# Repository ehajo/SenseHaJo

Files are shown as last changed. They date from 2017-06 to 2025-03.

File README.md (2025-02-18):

# SenseHaJo
Alle Infos über das SenseHaJo Projekt.

Die Youtube-Livestream Playlist befindet sich hier: <a href="https://www.youtube.com/playlist?list=PLOau4iU1BNa8n_ICx9ISsTIcdp01ndQ__">Playlist on Youtube</a>

Livestreams immer hier auf Twitch: <a href="https://www.twitch.tv/ehajo">Link zu Twitch</a>

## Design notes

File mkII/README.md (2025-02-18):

# SenseHaJo

Mark II ist die aktuellste Version des SenseHaJo-Projekts. Mathias aka Calm aka "der andere" hat in KiCAD ein komplettes Projekt hochgezogen.

Ich programmiere die Software mit ESPHome und mit Hilfe von ChatGPT.

Die Platine besitzt nun einen leistungsstarken ESP32 Prozessor.

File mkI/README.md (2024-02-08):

# SenseHaJo mkI

Mark 1 ist der erste Wurf der SenseHaJo. Wir haben die gesamte Hardware reverse engineered und eine komplett eigene Platine gebaut, die exakt in die original Maschine passt.

Aus historischen Gründen befindet sich noch ein Atmega32u2 auf der Platine, der ESP war damals noch nicht weit genug entwickelt, als dass das Sinn gemacht hätte.

Die gesamte Maschine ist galvanisch getrennt und hat einen USB-Anschluss zur zusätzlichen Ansteuerung über zB eine Hausautomatisierung.

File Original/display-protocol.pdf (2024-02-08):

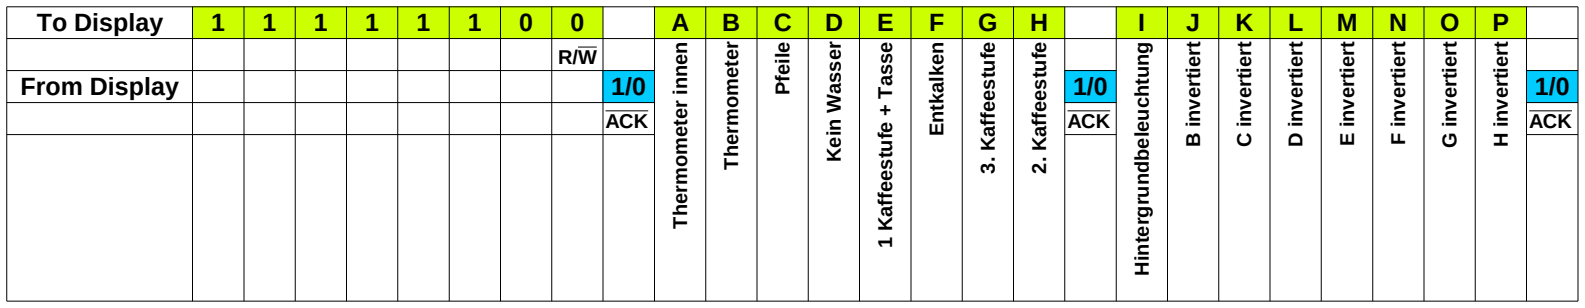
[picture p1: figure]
Thermometer innen; Thermometer; Pfeile; Kein Wasser; 1 Kaffeestufe + Tasse; Entkalken; 3. Kaffeestufe; 2. Kaffeestufe; Hintergrundbeleuchtung; B invertiert; C invertiert; D invertiert; E invertiert; F invertiert; G invertiert; H invertiert; ACK

To Display | 1 | 1 | 1 | 1 | 1 | 1 | 0 | 0 | | A | B | C | D | E | F | G | H | | I | J | K | L | M | N | O | P
From Display | | | | | | | | | 1/0 | | | | | | | | | 1/0 | | | | | | | | | 1/0

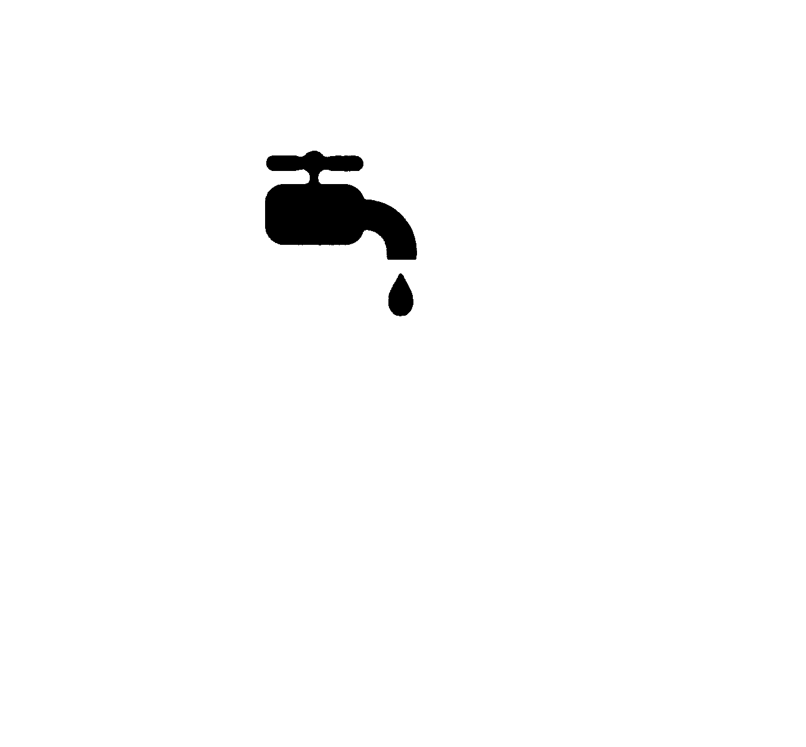
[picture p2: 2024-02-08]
Original/display-bilder/wasser-aus.png

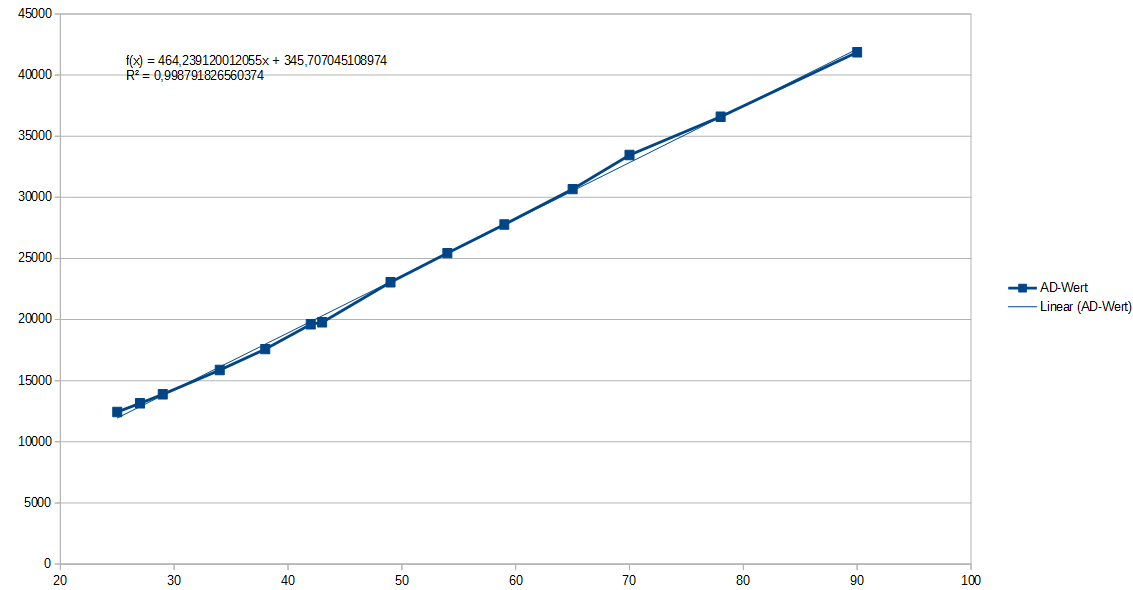
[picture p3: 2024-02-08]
Original/adc-temp.PNG

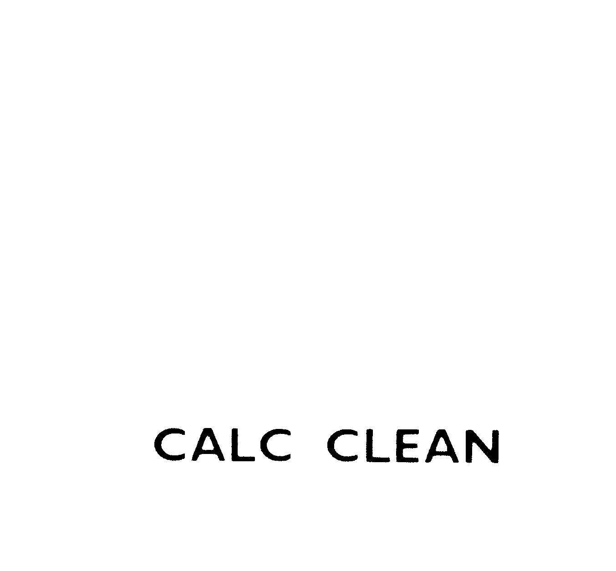
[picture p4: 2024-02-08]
Original/display-bilder/calcclean.png

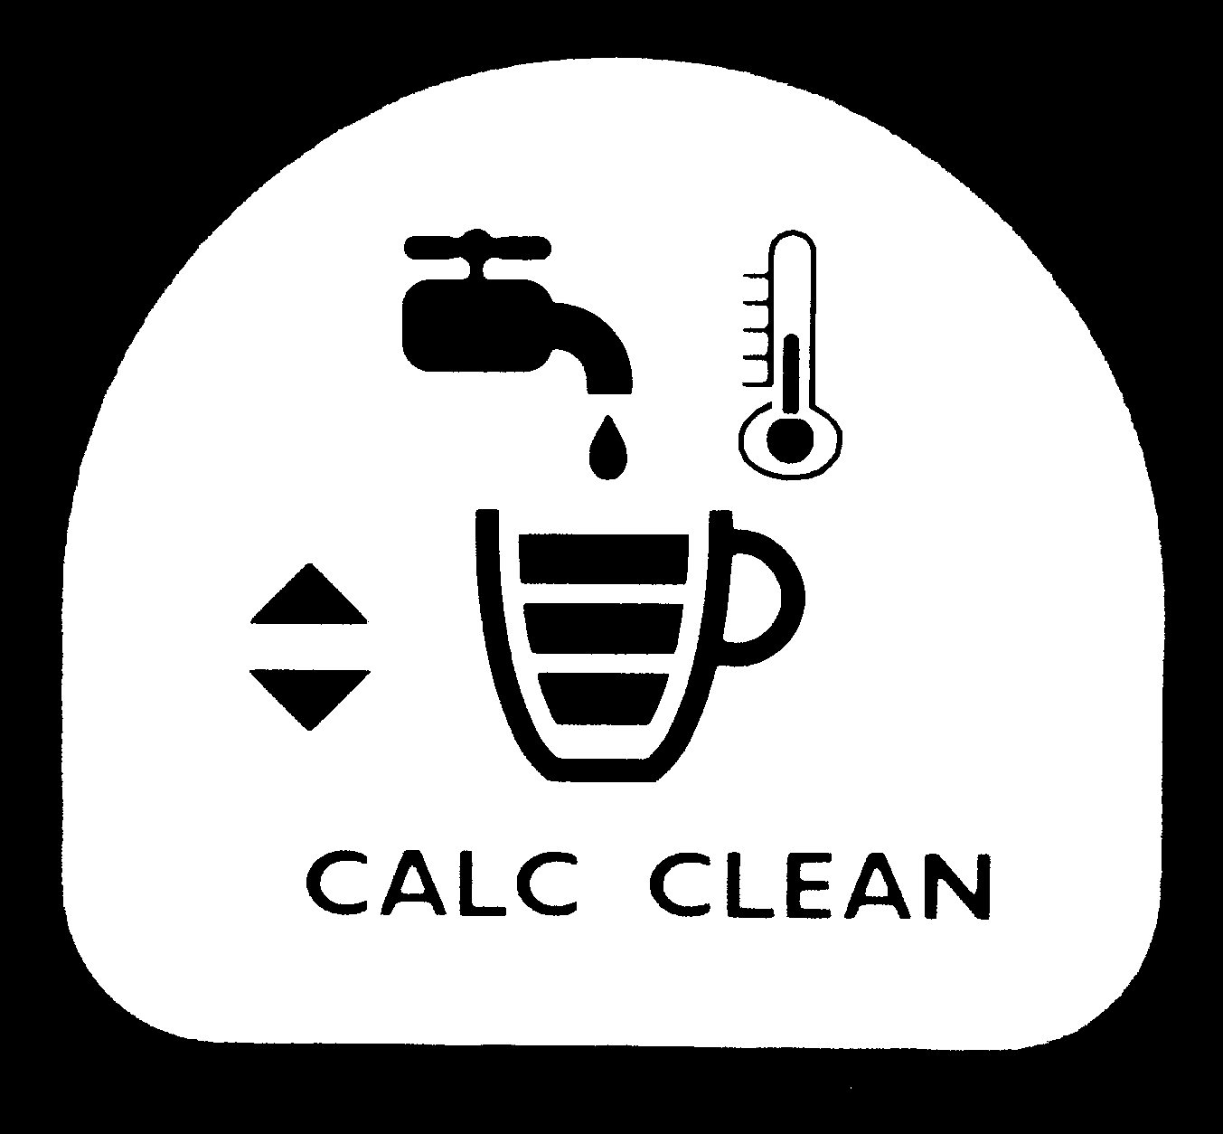
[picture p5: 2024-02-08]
Original/display-bilder/alles-an.png

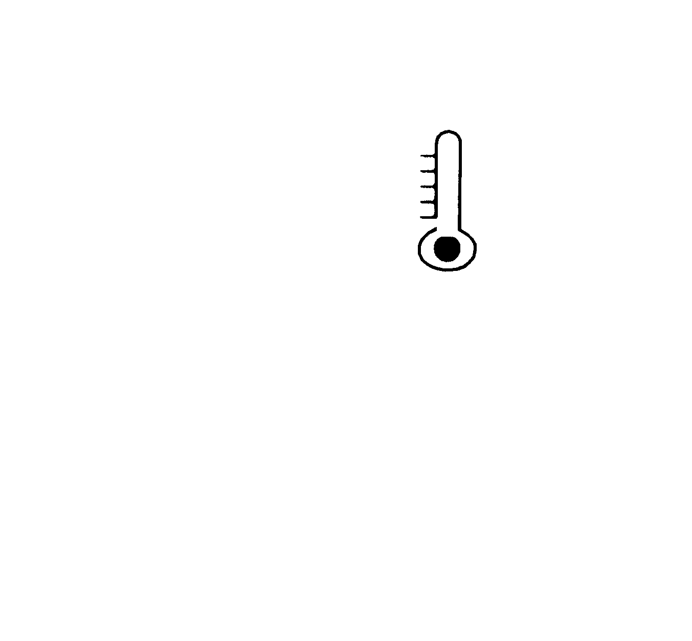
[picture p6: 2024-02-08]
Original/display-bilder/temp-2.png

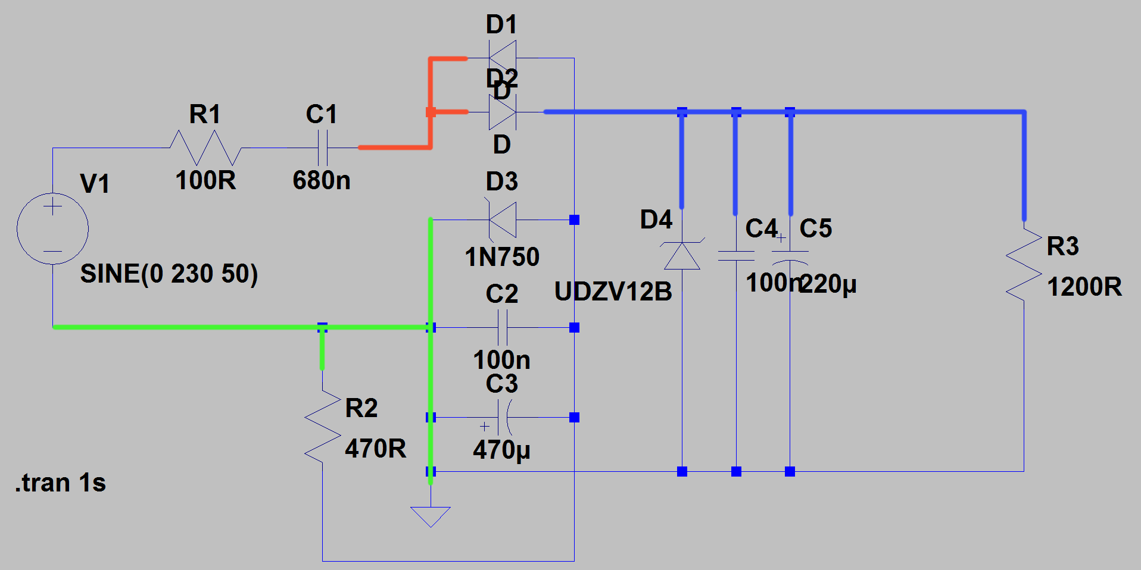
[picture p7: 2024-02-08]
Original/Simulation/schaltung.png

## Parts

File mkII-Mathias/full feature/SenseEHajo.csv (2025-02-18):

Source: | D:\NextCloud\KiCad\SensEhajo-KiCad\SenseEHajo\SenseEHajo.kicad_sch
Date: | 6/11/2023 4:29:25 PM
Tool: | Eeschema 7.0.1
Generator: | C:\Program Files\KiCad\6.0\bin\scripting\plugins/bom_csv_grouped_by_value_with_fp.py
Component Count: | 103
Ref | Qnty | Value | Cmp name | Footprint | Description | Vendor
C1, C3, | 2 | 1uF / 10V | C_Small | Capacitor_SMD:C_0805_2012Metric_Pad1.18x1.45mm_HandSolder | Unpolarized capacitor, small symbol
C2, C4, C5, C6, C7, C8, C14, C15, C16, C17, C19, C25, C26, C27, C28, | 15 | 100nF / 10V | C_Small | Capacitor_SMD:C_0805_2012Metric_Pad1.18x1.45mm_HandSolder | Unpolarized capacitor, small symbol
C9, | 1 | 10uF/10V | CP1_Small | Capacitor_SMD:CP_Elec_4x4.5
C10, | 1 | 1uF/25V | C_Small | Capacitor_SMD:C_0805_2012Metric_Pad1.18x1.45mm_HandSolder | Unpolarized capacitor, small symbol
C11, | 1 | 47uF/10V | CP1_Small | Capacitor_SMD:CP_Elec_5x5.3
C12, | 1 | 1uF/25V | C_Small | Capacitor_SMD:C_0805_2012Metric_Pad1.18x1.45mm_HandSolder | Unpolarized capacitor, small symbol
C13, | 1 | 10uF/25V | C_Small | Capacitor_SMD:C_0805_2012Metric_Pad1.18x1.45mm_HandSolder | Unpolarized capacitor, small symbol
C18, | 1 | 10uF / 10V | C_Small | Capacitor_SMD:C_0805_2012Metric_Pad1.18x1.45mm_HandSolder | Unpolarized capacitor, small symbol
D2, | 1 | D_Schottky | D_Schottky | Diode_SMD:D_SOD-523 | Schottky diode
D3, D6, D7, | 3 | WS2812B | WS2812B | LED_SMD:LED_WS2812B_PLCC4_5.0x5.0mm_P3.2mm | RGB LED with integrated controller
D4, | 1 | 1N4006 | 1N4006 | Diode_THT:D_DO-201AD_P15.24mm_Horizontal | 800V 1A General Purpose Rectifier Diode, DO-41
D5, | 1 | PMEG4010EGWX | D_Schottky | Diode_SMD:D_SOD-123 | Schottky diode
FB1, FB2, | 2 | Ferrite_Bead | Ferrite_Bead | Resistor_SMD:R_0805_2012Metric_Pad1.20x1.40mm_HandSolder
IC1, | 1 | AP3012 | AP3012 | Package_TO_SOT_SMD:SOT-23-5_HandSoldering
IC2, | 1 | MCP3221 | MCP3221 | Package_TO_SOT_SMD:SOT-23-5_HandSoldering
IC3, IC5, IC6, | 3 | 74LVC1G125 | 74LVC1G125 | SC-74A_SOT753:SC-74A
IC4, | 1 | K814P | K814P | Package_DIP:DIP-4_W7.62mm
IC7, | 1 | 74LVC1G10 | 74LVC1G10 | Package_TO_SOT_SMD:SOT-23-6_Handsoldering
J1, | 1 | Conn_01x02_Male | Conn_01x02_Male | Connector_PinHeader_2.54mm:PinHeader_1x02_P2.54mm_Vertical | Generic connector, single row, 01x02, script generated (kicad-library-utils/schlib/autogen/connector/)
J2, | 1 | REED | Conn_01x02_Male | Connector_PinHeader_2.54mm:PinHeader_1x02_P2.54mm_Vertical | Generic connector, single row, 01x02, script generated (kicad-library-utils/schlib/autogen/connector/)
J3, | 1 | RTC ( DS3231) | Conn_01x05 | Connector_PinHeader_2.54mm:PinHeader_1x05_P2.54mm_Vertical | Generic connector, single row, 01x05, script generated (kicad-library-utils/schlib/autogen/connector/)
J4, | 1 | Heizung L | Conn_01x01_Male | MountingHole:MountingHole_2.7mm_M2.5_DIN965_Pad_TopBottom | Generic connector, single row, 01x01, script generated (kicad-library-utils/schlib/autogen/connector/)
J5, | 1 | Pumpe L | Conn_01x01_Male | MountingHole:MountingHole_2.7mm_M2.5_DIN965_Pad_TopBottom | Generic connector, single row, 01x01, script generated (kicad-library-utils/schlib/autogen/connector/)
J6, | 1 | Conn_01x05 | Conn_01x05 | Connector_PinHeader_2.54mm:PinHeader_1x05_P2.54mm_Vertical | Generic connector, single row, 01x05, script generated (kicad-library-utils/schlib/autogen/connector/)
J7, | 1 | L | Conn_01x01_Male | MountingHole:MountingHole_2.7mm_M2.5_DIN965_Pad_TopBottom | Generic connector, single row, 01x01, script generated (kicad-library-utils/schlib/autogen/connector/)
J8, | 1 | N | Conn_01x01_Male | MountingHole:MountingHole_2.7mm_M2.5_DIN965_Pad_TopBottom | Generic connector, single row, 01x01, script generated (kicad-library-utils/schlib/autogen/connector/)
J9, | 1 | Prog | Conn_01x05 | Connector_PinHeader_2.54mm:PinHeader_1x05_P2.54mm_Vertical | Generic connector, single row, 01x05, script generated (kicad-library-utils/schlib/autogen/connector/)
JP1, JP2, | 2 | Jumper_2_Open | Jumper_2_Open | Jumper:SolderJumper-2_P1.3mm_Open_RoundedPad1.0x1.5mm | Jumper, 2-pole, open
L1, | 1 | 10uH | L_Small | Inductor_SMD:L_Wuerth_MAPI-3015 | Inductor, small symbol
PS1, | 1 | HLK-PM01 | HLK-PM01 | Converter_ACDC:Converter_ACDC_HiLink_HLK-PMxx | Compact AC/DC board mount power module 3W 5V
Q1, | 1 | BSS138 | BSS138 | Package_TO_SOT_SMD:SOT-23 | 50V Vds, 0.22A Id, N-Channel MOSFET, SOT-23
R1, R5, R8, R9, R12, R13, R14, R21, R22, R24, R25, R26, R27, R28, R30, R31, R32, R33, R34, R35, R36, | 21 | 10k | R_Small | Resistor_SMD:R_0805_2012Metric_Pad1.20x1.40mm_HandSolder | Resistor, small symbol
R2, | 1 | 2k2 | R_Small | Resistor_SMD:R_0805_2012Metric_Pad1.20x1.40mm_HandSolder | Resistor, small symbol
R3, | 1 | 1k8 | R_Small | Resistor_SMD:R_0805_2012Metric_Pad1.20x1.40mm_HandSolder | Resistor, small symbol
R4, | 1 | 10k (DNP) | R_Small | Resistor_SMD:R_0805_2012Metric_Pad1.20x1.40mm_HandSolder | Resistor, small symbol
R6, R7, | 2 | 100k | R_Small | Resistor_THT:R_Axial_DIN0207_L6.3mm_D2.5mm_P7.62mm_Horizontal | Resistor, small symbol
R10, R11, | 2 | 150R | R_Small | Resistor_SMD:R_0805_2012Metric_Pad1.20x1.40mm_HandSolder | Resistor, small symbol
R15, R17, | 2 | 360R | R_Small | Resistor_THT:R_Axial_DIN0207_L6.3mm_D2.5mm_P7.62mm_Horizontal | Resistor, small symbol
R16, R18, | 2 | 330R | R_Small | Resistor_THT:R_Axial_DIN0207_L6.3mm_D2.5mm_P7.62mm_Horizontal | Resistor, small symbol
R20, R37, R38, R39, | 4 | 1k | R_Small | Resistor_SMD:R_0805_2012Metric_Pad1.20x1.40mm_HandSolder | Resistor, small symbol
R23, | 1 | 43.2k | R_Small | Resistor_SMD:R_0805_2012Metric_Pad1.20x1.40mm_HandSolder | Resistor, small symbol
R29, | 1 | 100R | R_Small | Resistor_SMD:R_0805_2012Metric_Pad1.20x1.40mm_HandSolder | Resistor, small symbol
SW2, | 1 | SW1 ( Boot ) | SW_Push | Button_Switch_THT:SW_PUSH_6mm | Push button switch, generic, two pins
SW3, | 1 | MACHINE_SW2 | SW_Push | Button_Switch_THT:SW_PUSH_6mm | Push button switch, generic, two pins
SW4, | 1 | MACHINE_SW3 | SW_Push | Button_Switch_THT:SW_PUSH_6mm | Push button switch, generic, two pins
T1, T2, | 2 | QJ8025 | QJ8025 | Package_TO_SOT_SMD:TO-263-3_TabPin2
TP1, TP2, | 2 | TestPoint | TestPoint | TestPoint:TestPoint_Pad_D2.0mm | test point
U1, | 1 | ESP32-WROOM-32 | ESP32-WROOM-32 | ESP32_Handsolder:ESP32-WROOM-32_HandSolder | RF Module, ESP32-D0WDQ6 SoC, Wi-Fi 802.11b/g/n, Bluetooth, BLE, 32-bit, 2.7-3.6V, onboard antenna, SMD
U2, U5, | 2 | MCP6001-OT | MCP6001-OT | Package_TO_SOT_SMD:SOT-23-5 | 1MHz, Low-Power Op Amp, SOT-23-5
U3, U4, | 2 | MOC3043M | MOC3043M | Package_DIP:DIP-6_W7.62mm | Zero Cross Opto-Triac, Vdrm 400V, Ift 5mA, DIP6
U6, | 1 | LM1117-3.3 | LM1117-3.3 | Package_TO_SOT_SMD:SOT-223-3_TabPin2 | 800mA Low-Dropout Linear Regulator, 3.3V fixed output, TO-220/TO-252/TO-263/SOT-223

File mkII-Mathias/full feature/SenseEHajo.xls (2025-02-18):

Ref | Qty | Value | Footprint | Datasheet | Order No. Farnell | Order No. Mouser
C1 C6 | 2 | 100nF / 25V | Capacitor_SMD:C_0805_2012Metric_Pad1.15x1.40mm_HandSolder | ~ |  | 710-885012207098
C2 C5 | 2 | 100nF / 10V | Capacitor_SMD:C_0805_2012Metric_Pad1.15x1.40mm_HandSolder | ~ |  | 710-885012207098
C3 | 1 | 1uF / 10V | Capacitor_SMD:C_0805_2012Metric_Pad1.15x1.40mm_HandSolder | ~ |  | 80-C0805C105Z4V
C4 | 1 | 10uF / 25V | Capacitor_SMD:C_0805_2012Metric_Pad1.15x1.40mm_HandSolder | ~ |  | 0805X106K250CT
C7 C8 C14 C15 C16 C17 C19 | 7 | 100nF | Capacitor_SMD:C_0805_2012Metric_Pad1.15x1.40mm_HandSolder | ~ |  | 710-885012207098
C9 | 1 | 10uF/10V | Capacitor_SMD:C_0805_2012Metric_Pad1.15x1.40mm_HandSolder | ~ |  | 710-885012107010
C10 | 1 | 1uF/25V | Capacitor_SMD:C_0805_2012Metric_Pad1.15x1.40mm_HandSolder | ~ |  | 963-TMK212B7105KG-T
C11 | 1 | 47uF/10V | Capacitor_SMD:C_0805_2012Metric_Pad1.15x1.40mm_HandSolder | ~ |  | LMK316BC6476ML-T
C12 | 1 | 1uF/25V | Capacitor_SMD:C_0805_2012Metric_Pad1.15x1.40mm_HandSolder | ~ |  | 963-TMK212B7105KG-T
C13 | 1 | 10uF/25V | Capacitor_SMD:C_0805_2012Metric_Pad1.15x1.40mm_HandSolder | ~ |  | TMK212BBJ106KG-T
C18 | 1 | 10uF | Capacitor_SMD:C_0805_2012Metric_Pad1.15x1.40mm_HandSolder | ~ |  | 0805X106K250CT
D4 | 1 | 1N4006 | Diode_THT:D_DO-201AD_P15.24mm_Horizontal | http://www.vishay.com/docs/88503/1n4001.pdf
D5 | 1 | PMEG4010EGWX | Diode_SMD:D_SOD-123 | ~ |  | 841-PMEG4010EGWX
FB1 | 1 | Ferrite_Bead | Capacitor_SMD:C_0805_2012Metric_Pad1.15x1.40mm_HandSolder | ~ |  | 710-742792093
IC1 | 1 | AP3012 | Package_TO_SOT_SMD:SOT-23-5_HandSoldering |  |  | 621-AP3012KTR-G1
IC2 | 1 | MCP3221 | Package_TO_SOT_SMD:SOT-23-5_HandSoldering |  | 1332098 | 579-MCP3221A5T-E/OT
IC3 | 1 | SN74AUP1G08-Q1 | Package_TO_SOT_SMD:SOT-23-5_HandSoldering |  |  | 595-SN74AUP1G08DBVR
IC4 | 1 | K814P | Package_DIP:DIP-4_W7.62mm |  |  | 782-K814P
J1 | 1 | Conn_01x02_Male | Connector_PinHeader_2.54mm:PinHeader_1x02_P2.54mm_Vertical | ~
J2 | 1 | REED | Connector_PinHeader_2.54mm:PinHeader_1x02_P2.54mm_Vertical | ~
J3 | 1 | RTC ( DS3231) | Connector_PinHeader_2.54mm:PinHeader_1x05_P2.54mm_Vertical | ~
J4 | 1 | Heizung | Connector_PinHeader_2.54mm:PinHeader_1x01_P2.54mm_Vertical | ~
J5 | 1 | Pumpe | Connector_PinHeader_2.54mm:PinHeader_1x01_P2.54mm_Vertical | ~
J6 | 1 | Conn_01x05 | Connector_PinHeader_2.54mm:PinHeader_1x05_P2.54mm_Vertical | ~
J7 | 1 | L | Connector_PinHeader_2.54mm:PinHeader_1x01_P2.54mm_Vertical | ~
J8 | 1 | N | Connector_PinHeader_2.54mm:PinHeader_1x01_P2.54mm_Vertical | ~
J9 | 1 | Prog | Connector_PinHeader_2.54mm:PinHeader_1x05_P2.54mm_Vertical | ~
L1 | 1 | 10uH | Inductor_SMD:L_Wuerth_MAPI-3015 | ~ |  | 710-74438335100
LED1 LED2 LED3 | 3 | WS2812D | WS2812D:WS2812D_THT
PS1 | 1 | HLK-PM01 | Converter_ACDC:Converter_ACDC_HiLink_HLK-PMxx | http://www.hlktech.net/product_detail.php?ProId=54
Q1 | 1 | BSS138 | Package_TO_SOT_SMD:SOT-23 | https://www.fairchildsemi.com/datasheets/BS/BSS138.pdf
R1 R4 | 2 | 10k | Resistor_SMD:R_0805_2012Metric_Pad1.15x1.40mm_HandSolder | ~ |  | CRCW080510K0FKEAC
R2 R30 | 2 | 2k2 | Resistor_SMD:R_0805_2012Metric_Pad1.15x1.40mm_HandSolder | ~ |  | 71-CRCW08052K20FKEAC
R3 R27 | 2 | 1k8 | Resistor_SMD:R_0805_2012Metric_Pad1.15x1.40mm_HandSolder | ~ |  | 71-CRCW0805-1.8K-E3
R5 | 1 | 10k | Resistor_SMD:R_0805_2012Metric_Pad1.15x1.40mm_HandSolder | ~ |  | 71-CRCW080510K0FKEAC
R6 R7 | 2 | 100k | Resistor_THT:R_Axial_DIN0207_L6.3mm_D2.5mm_P7.62mm_Horizontal | ~ |  | 603-MFR-25FBF52-100K
R10 | 1 | 150R | Resistor_SMD:R_0805_2012Metric_Pad1.15x1.40mm_HandSolder | ~
R11 | 1 | 150R | Resistor_SMD:R_0805_2012Metric_Pad1.15x1.40mm_HandSolder | ~ |  | CRCW0805150KFKEA
R12 R24 | 2 | 4k7 | Resistor_SMD:R_0805_2012Metric_Pad1.15x1.40mm_HandSolder | ~ |  | CRCW08054K70FKEBC
R13 R14 R21 R22 | 4 | 2k2 | Resistor_SMD:R_0805_2012Metric_Pad1.15x1.40mm_HandSolder | ~ |  | CRCW08052K20FKEAC
R15 R17 | 2 | 360R | Resistor_THT:R_Axial_DIN0207_L6.3mm_D2.5mm_P7.62mm_Horizontal | ~ |  | 71-CCF07360KGKE36
R16 | 1 | 330R | Resistor_THT:R_Axial_DIN0207_L6.3mm_D2.5mm_P7.62mm_Horizontal | ~ |  | CCF07330RJKE36
R18 | 1 | 330R | Resistor_THT:R_Axial_DIN0207_L6.3mm_D2.5mm_P7.62mm_Horizontal | ~ |  | 71-CCF07330RJKE36
R19 R20 | 2 | 15k | Resistor_SMD:R_0805_2012Metric_Pad1.15x1.40mm_HandSolder | ~ |  | CRCW080515K0FKEBC
R23 | 1 | 39k | Resistor_SMD:R_0805_2012Metric_Pad1.15x1.40mm_HandSolder | ~ |  | CRCW080539K0FKEAC
R25 | 1 | 1k | Resistor_SMD:R_0805_2012Metric_Pad1.15x1.40mm_HandSolder | ~ |  | 71-CRCW08051K00FKEAC
R26 | 1 | 3k9 | Resistor_SMD:R_0805_2012Metric_Pad1.15x1.40mm_HandSolder | ~ |  | 71-CRCW0805-3.92K-E3
R28 | 1 | 3k3 | Resistor_SMD:R_0805_2012Metric_Pad1.15x1.40mm_HandSolder | ~ |  | 71-CRCW08053K30FKEAC
R29 | 1 | 2k2 | Resistor_SMD:R_0805_2012Metric_Pad1.15x1.40mm_HandSolder | ~ |  | 71-CRCW08052K20FKEAC
SW1 | 1 | Reset | Button_Switch_THT:SW_PUSH_6mm | ~
SW2 | 1 | SW1 ( Boot ) | Button_Switch_THT:SW_PUSH_6mm | ~
SW3 | 1 | SW2 | Button_Switch_THT:SW_PUSH_6mm | ~
SW4 | 1 | SW3 | Button_Switch_THT:SW_PUSH_6mm | ~
T1 | 1 | QJ8025 | Package_TO_SOT_SMD:TO-263-3_TabPin2
T2 | 1 | QJ8025 | Package_TO_SOT_SMD:TO-263-3_TabPin2 |  |  | 576-QJ8025NH4RP
U1 | 1 | ESP32-WROOM-32 | RF_Module:ESP32-WROOM-32 | https://www.espressif.com/sites/default/files/documentation/esp32-wroom-32_datasheet_en.pdf
U2 | 1 | MCP6001-OT | Package_TO_SOT_SMD:SOT-23-5 | http://ww1.microchip.com/downloads/en/DeviceDoc/21733j.pdf | 4974992 | 579-MCP6001T-I/OT
U3 U4 | 2 | MOC3043M | Package_DIP:DIP-6_W7.62mm | http://www.fairchildsemi.com/ds/MO/MOC3031M.pdf |  | 512-MOC3043M
U5 | 1 | TCA9544A | Package_SO:TSSOP-20_4.4x6.5mm_P0.65mm | http://www.ti.com/lit/ds/symlink/tca9544a.pdf |  | 595-TCA9544APWR
U6 | 1 | LM1117-3.3 | Package_TO_SOT_SMD:SOT-223 | http://www.ti.com/lit/ds/symlink/lm1117.pdf |  | 926-LM1117MPX3.3NOPB
BOM made with KICAD_BOM_WIZARD (https://github.com/HashDefineElectronics/KiCad_BOM_Wizard.git)
Generated 20.03.2020 17:53:38

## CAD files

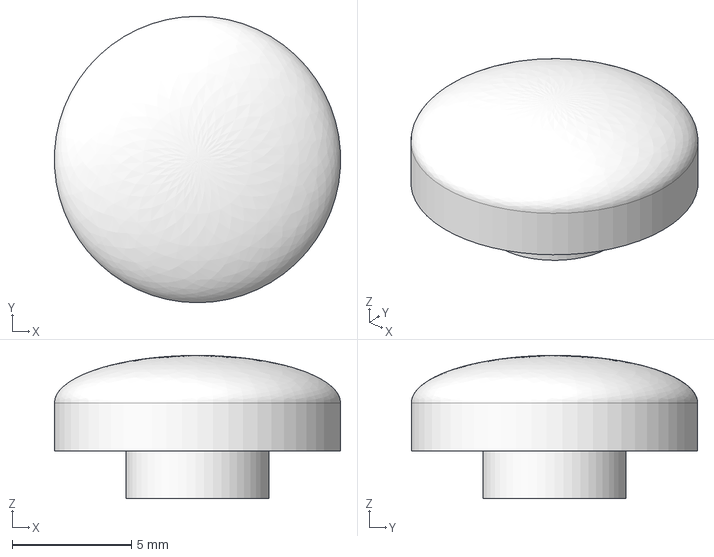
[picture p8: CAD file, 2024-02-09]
mkI/Hardware/CAD/taster-mit-nupsi.stp
12.0 x 12.0 x 6.00 mm

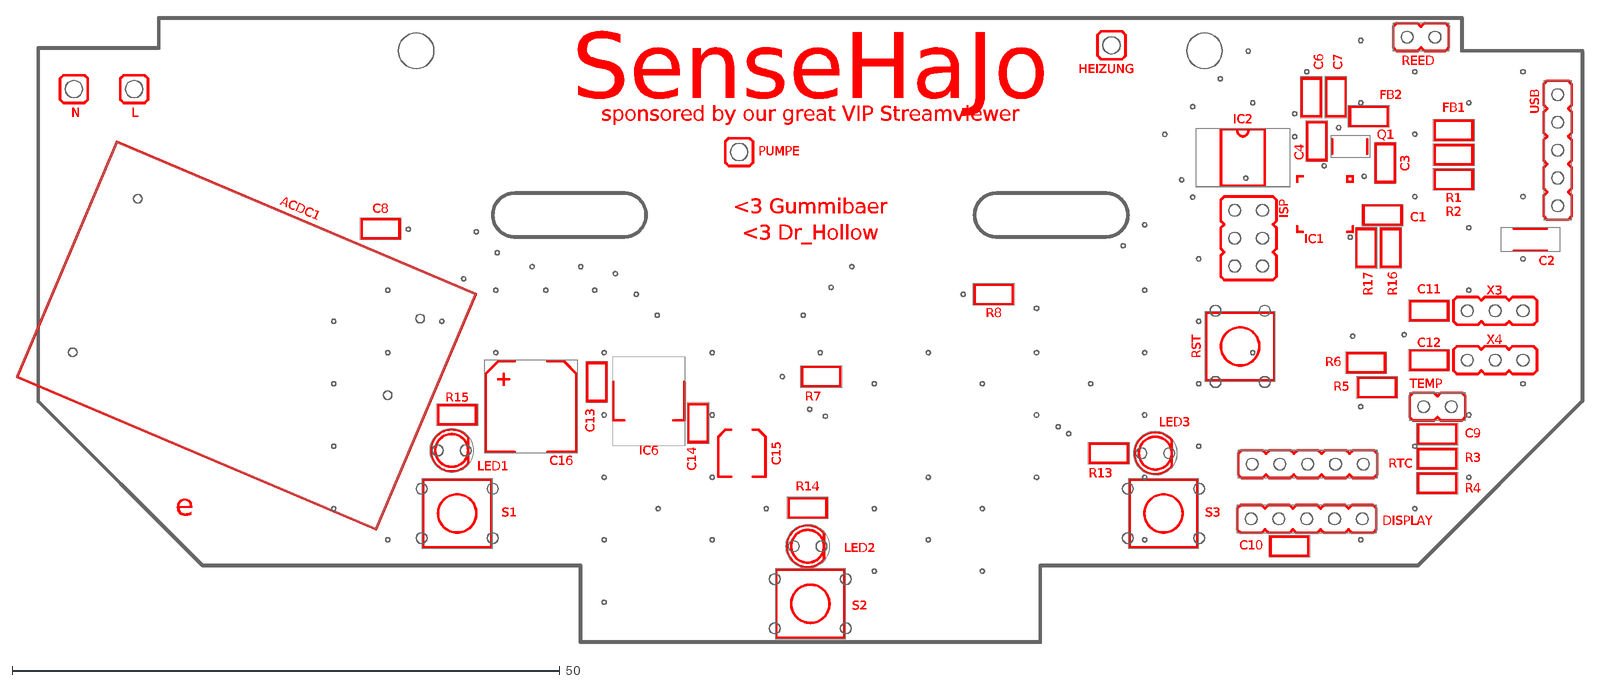
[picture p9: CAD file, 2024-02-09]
mkI/Hardware/senseo-v2_001.dxf
<3 Gummibaer
<3 Dr_Hollow
sponsored by our great VIP Streamviewer
SenseHaJo
e
N
L
USB
REED
RTC
HEIZUNG
PUMPE
ACDC1
ISP
RST
C16
C15
C14
C13
IC6
R17
R16
C12
C11
X4
X3
R15
R14
R13
LED3
LED2
LED1
S3
S2
S1
R8
R7
C10
DISPLAY
R6
R5
R4
R3
C9
TEMP
IC2
C8
C7
FB2
C6
C4
C3
FB1
R2
R1
C2
C1
Q1
IC1

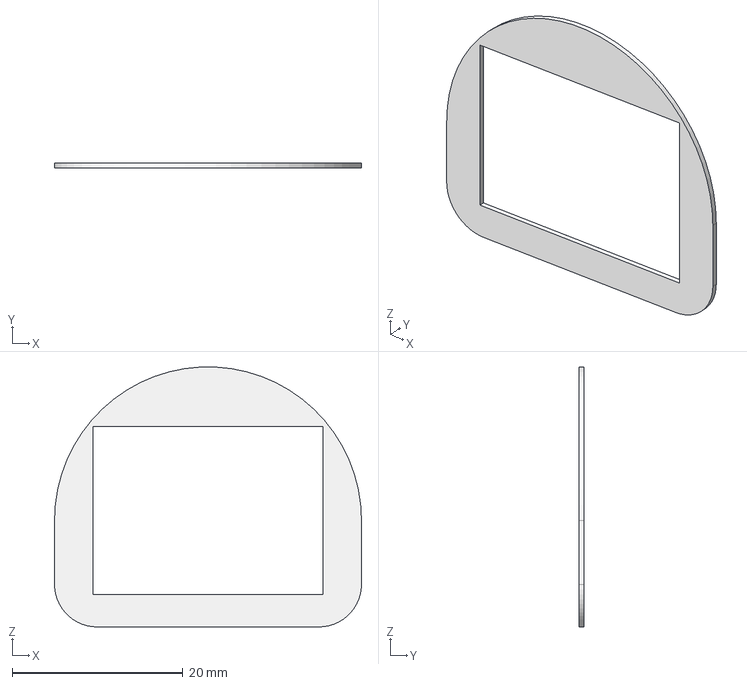
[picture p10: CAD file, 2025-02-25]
mkII/CAD/rahmen-display.stp
36.0 x 0.6 x 30.5 mm

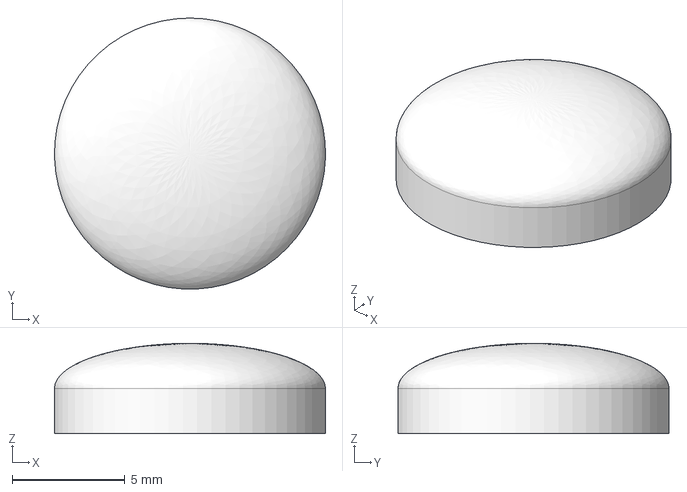
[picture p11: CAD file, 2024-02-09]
mkI/Hardware/CAD/taster-ohne-nupsi.stp
12.0 x 12.0 x 4.00 mm

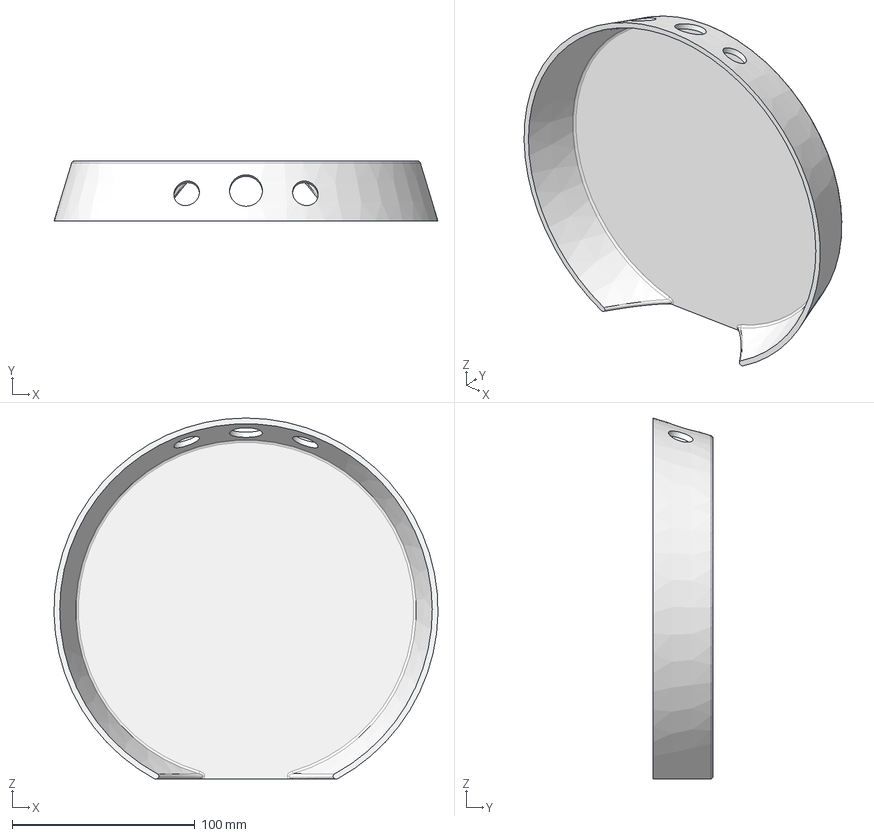
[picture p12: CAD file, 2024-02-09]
mkI/Hardware/CAD/3d-abdeckung.stp
210.2 x 33.0 x 197.6 mm

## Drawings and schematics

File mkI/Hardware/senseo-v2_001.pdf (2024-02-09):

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

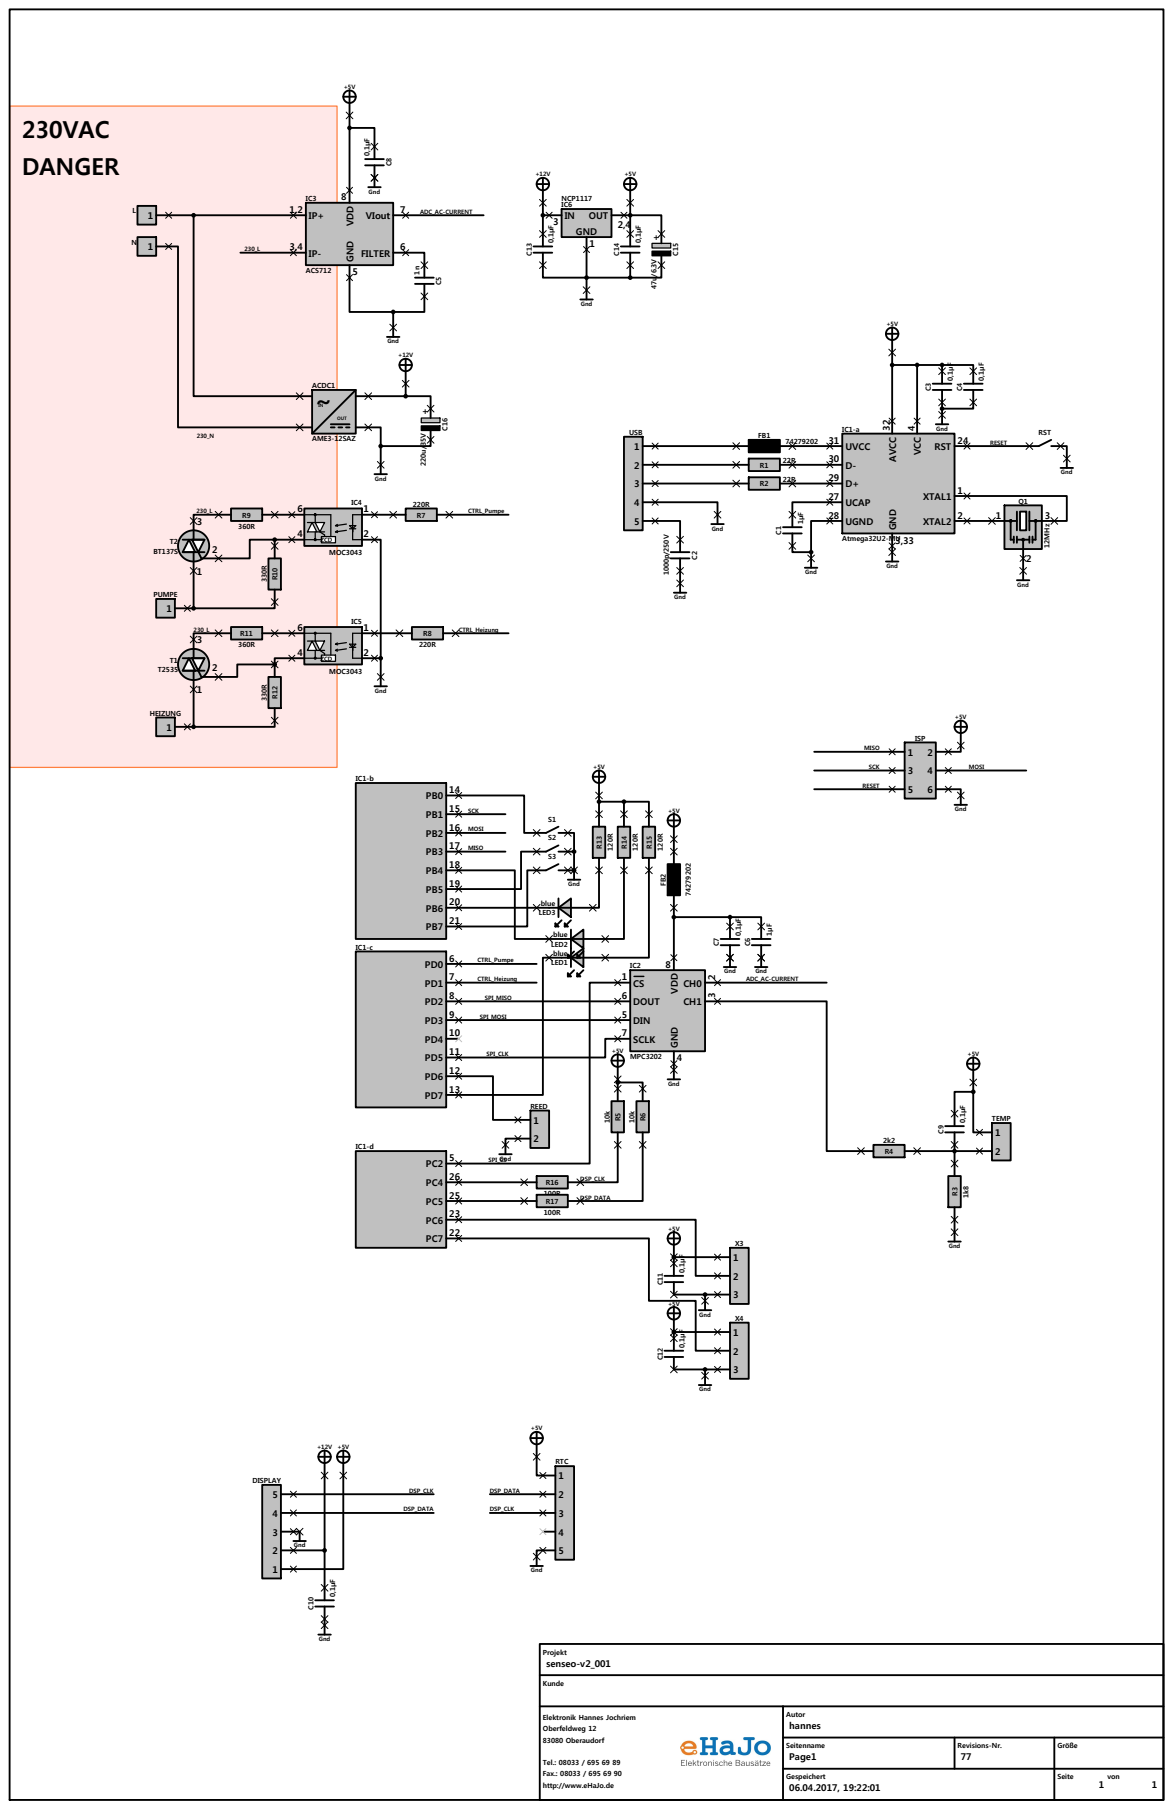
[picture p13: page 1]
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

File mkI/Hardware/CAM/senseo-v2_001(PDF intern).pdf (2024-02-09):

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

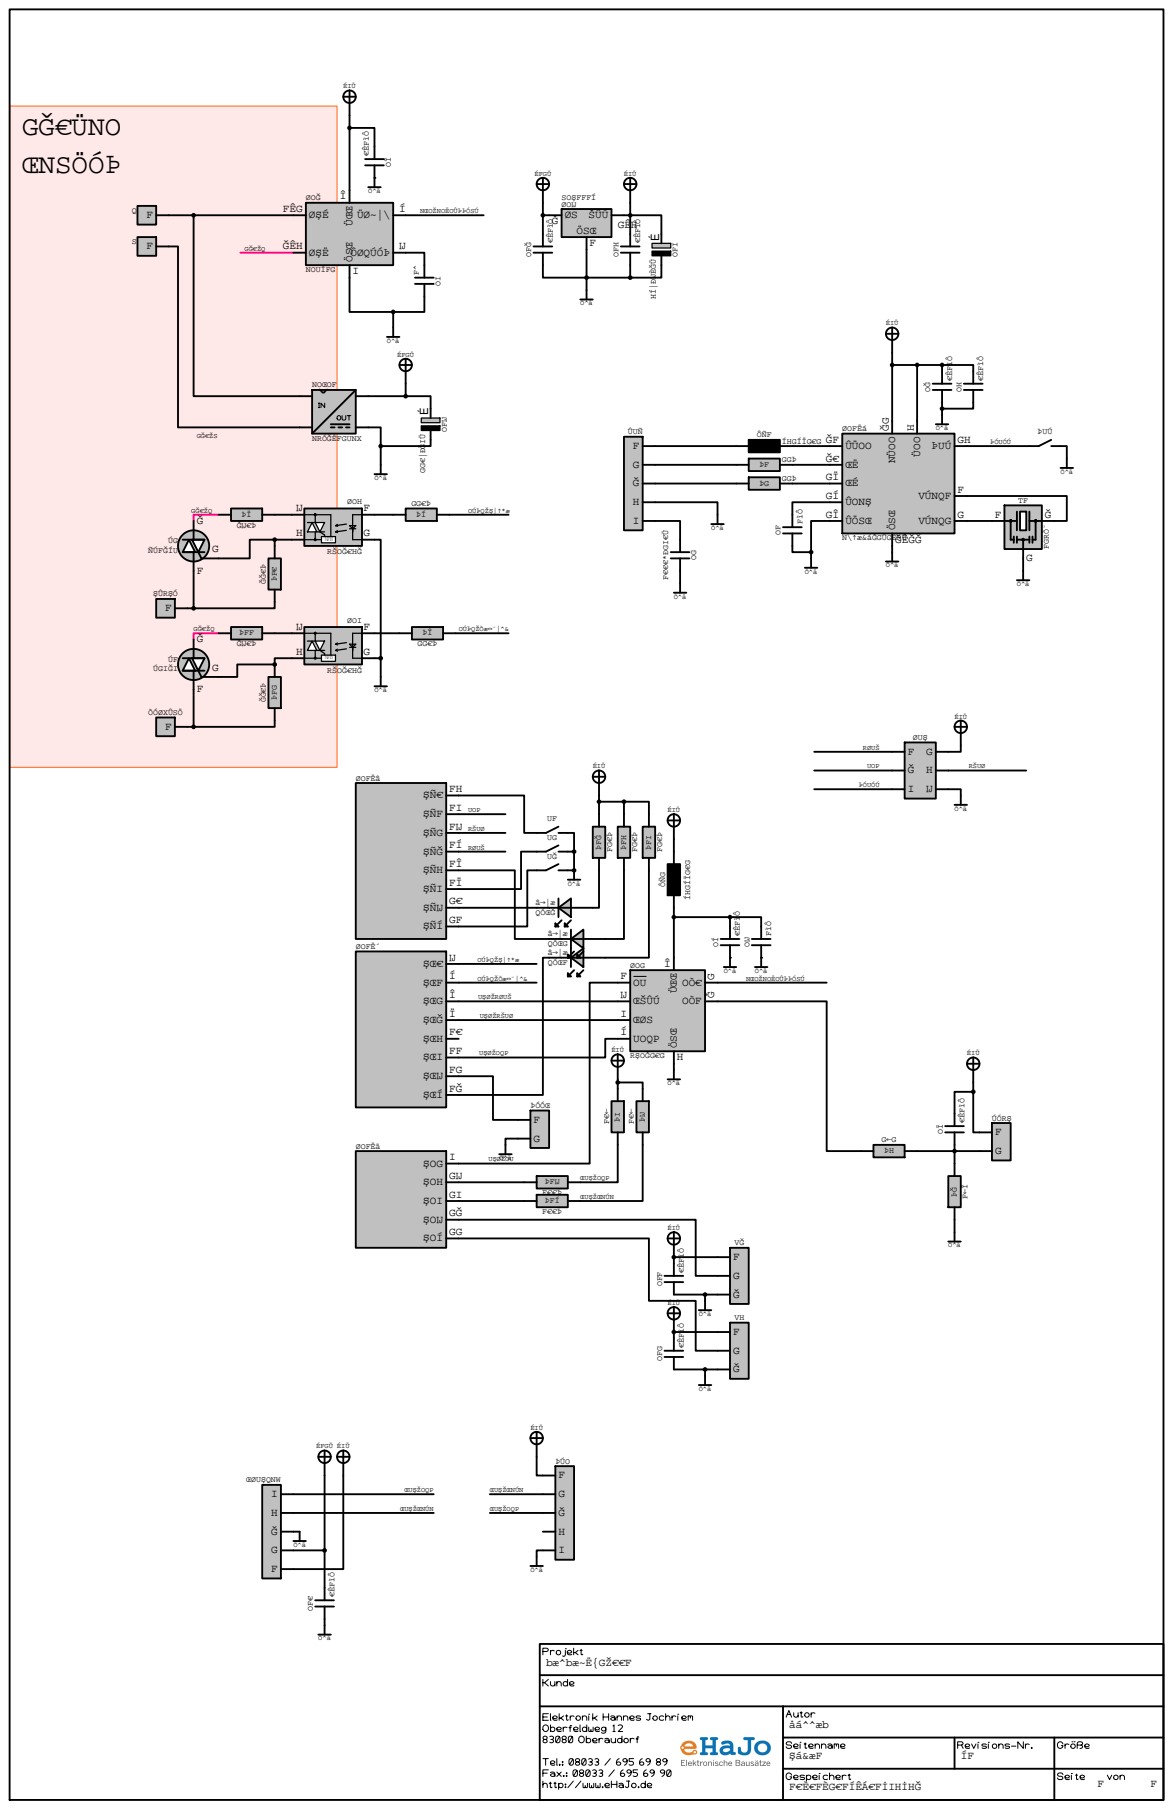
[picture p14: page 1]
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

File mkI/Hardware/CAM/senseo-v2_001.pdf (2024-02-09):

# HEIZUNG

L

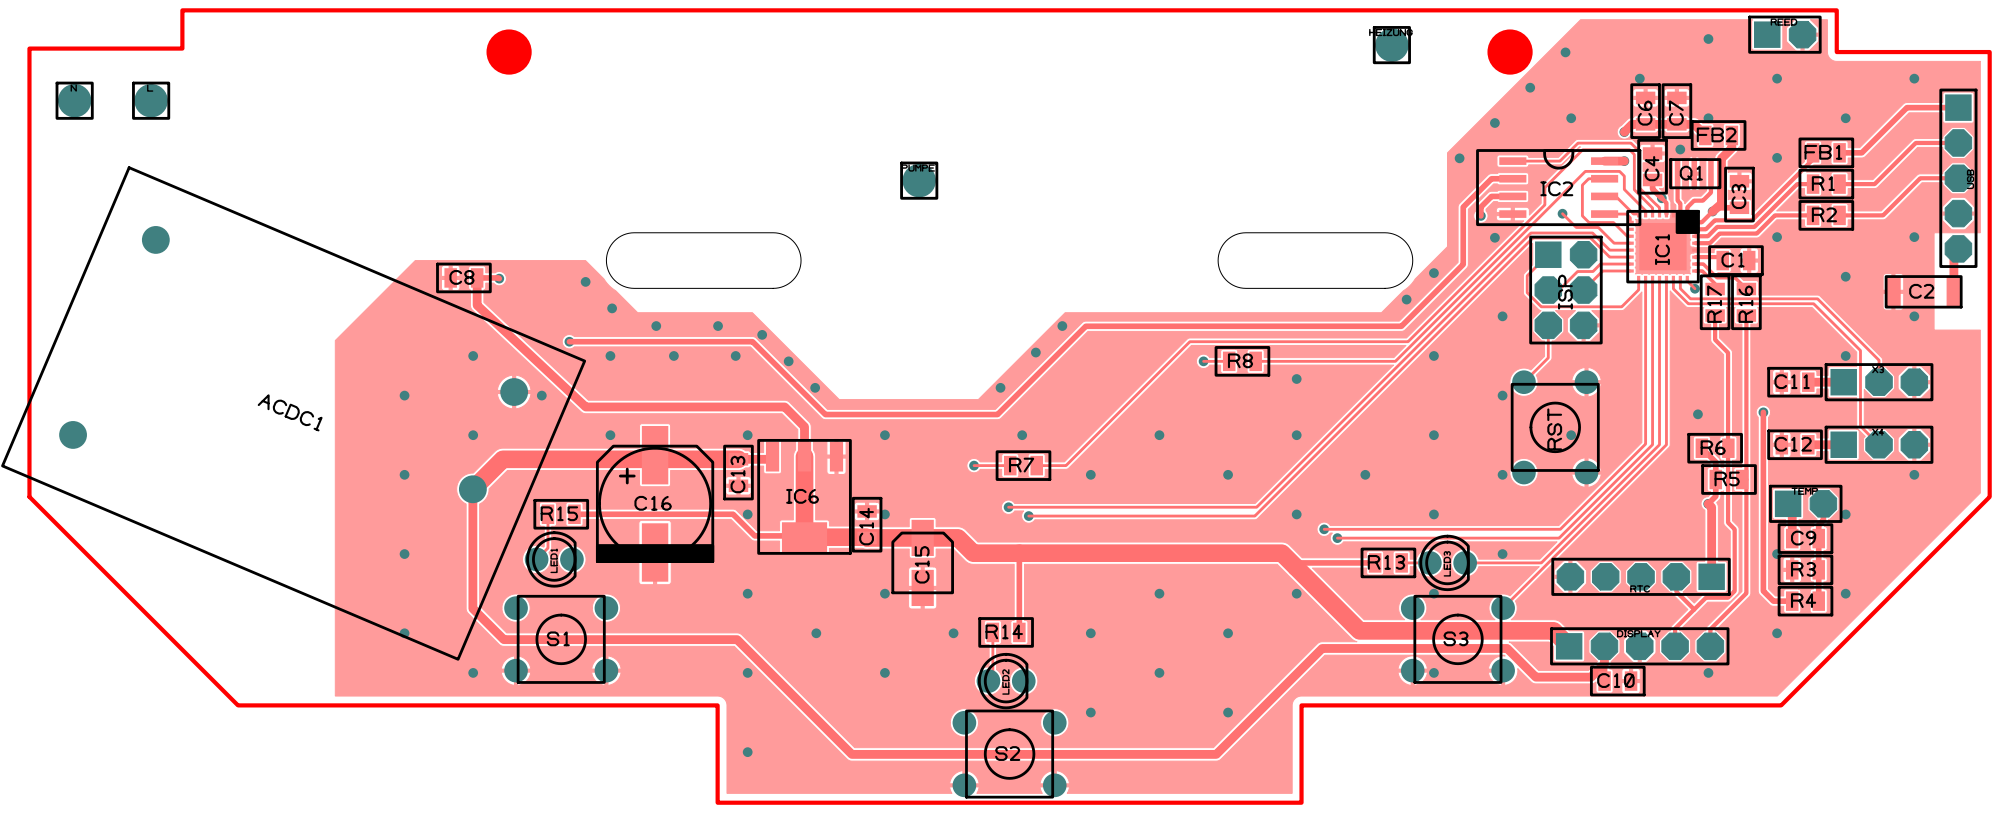
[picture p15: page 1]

L

# REED

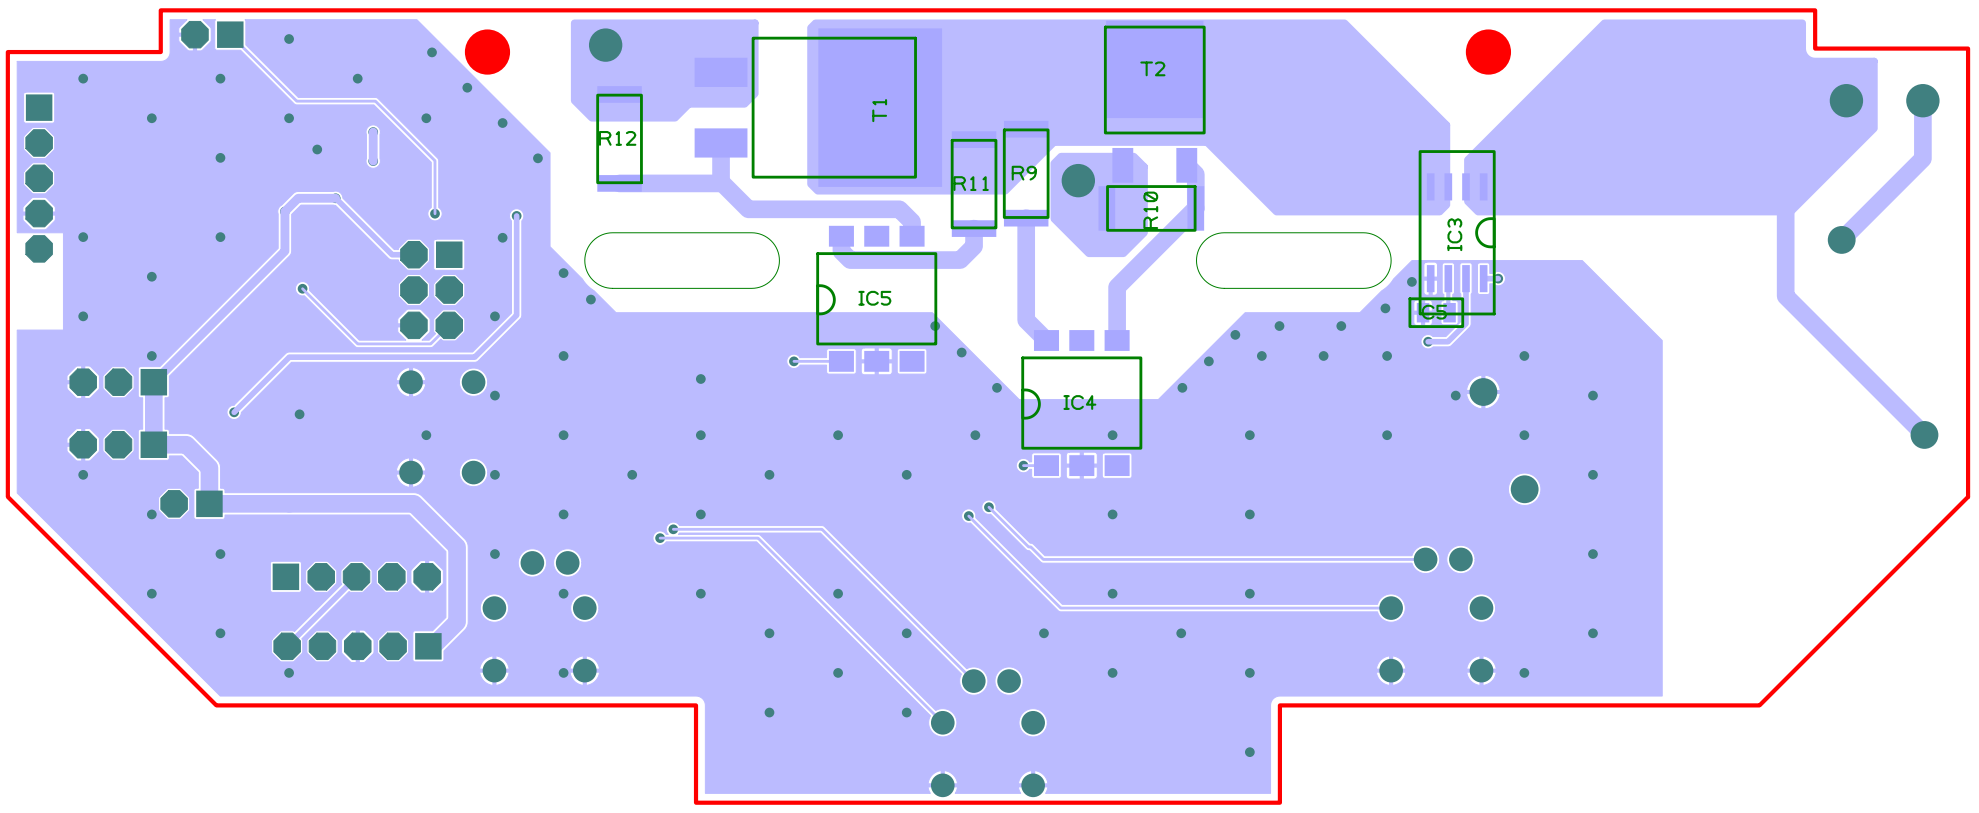
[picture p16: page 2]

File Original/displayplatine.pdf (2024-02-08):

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

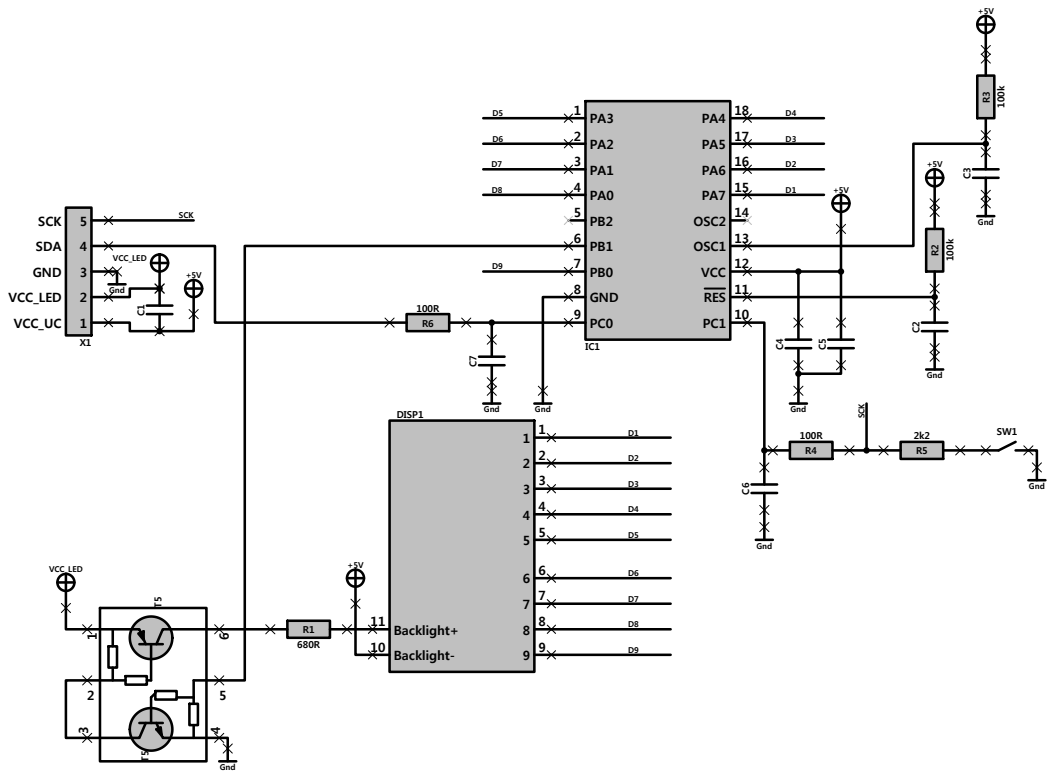
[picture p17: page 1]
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

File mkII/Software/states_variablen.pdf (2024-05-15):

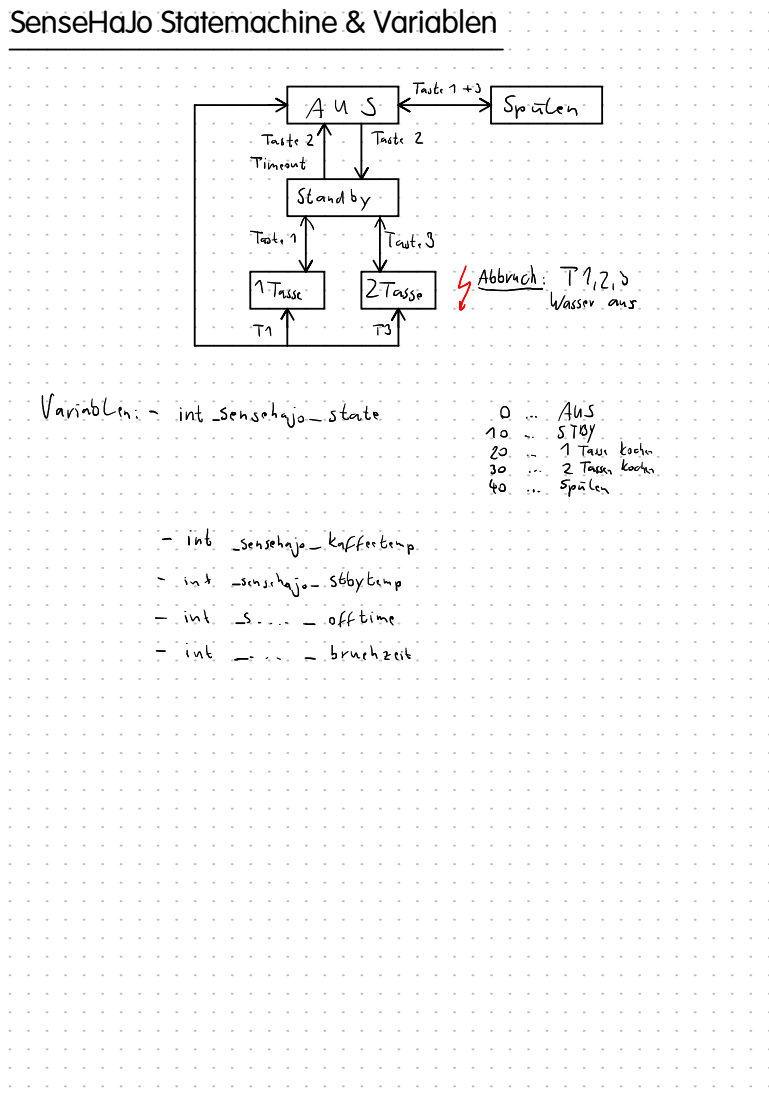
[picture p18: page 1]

SenseHaJo Statemachine & Variablen

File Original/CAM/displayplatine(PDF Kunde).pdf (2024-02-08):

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

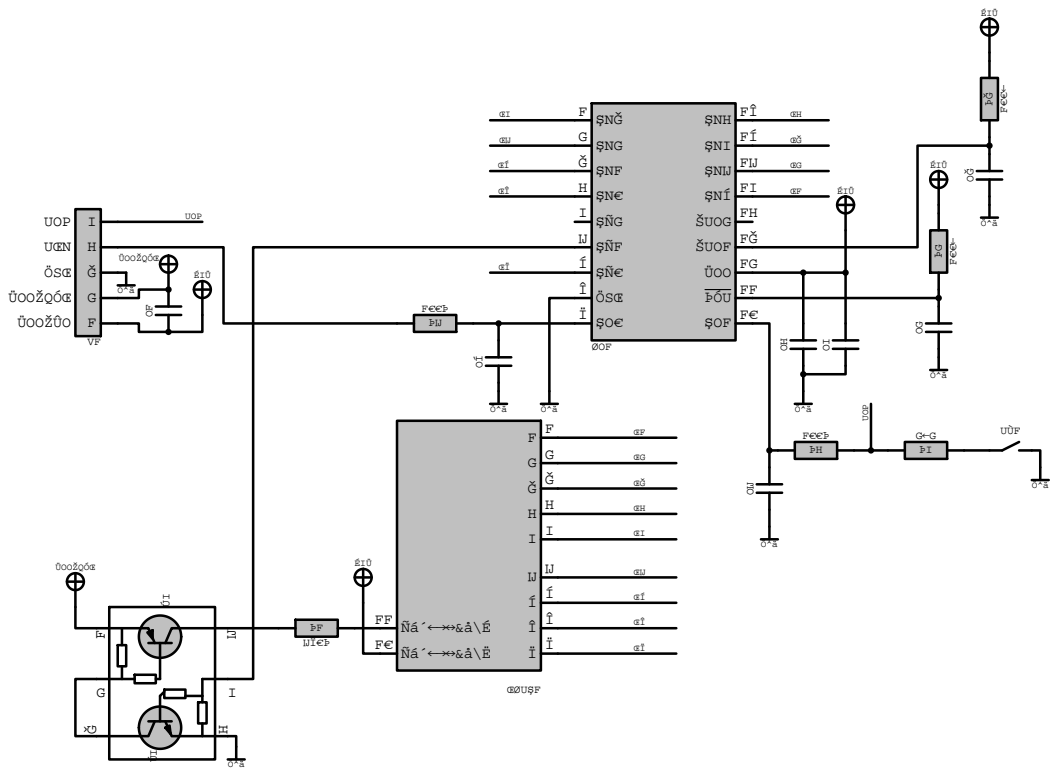
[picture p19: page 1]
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

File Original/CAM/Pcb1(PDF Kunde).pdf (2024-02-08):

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

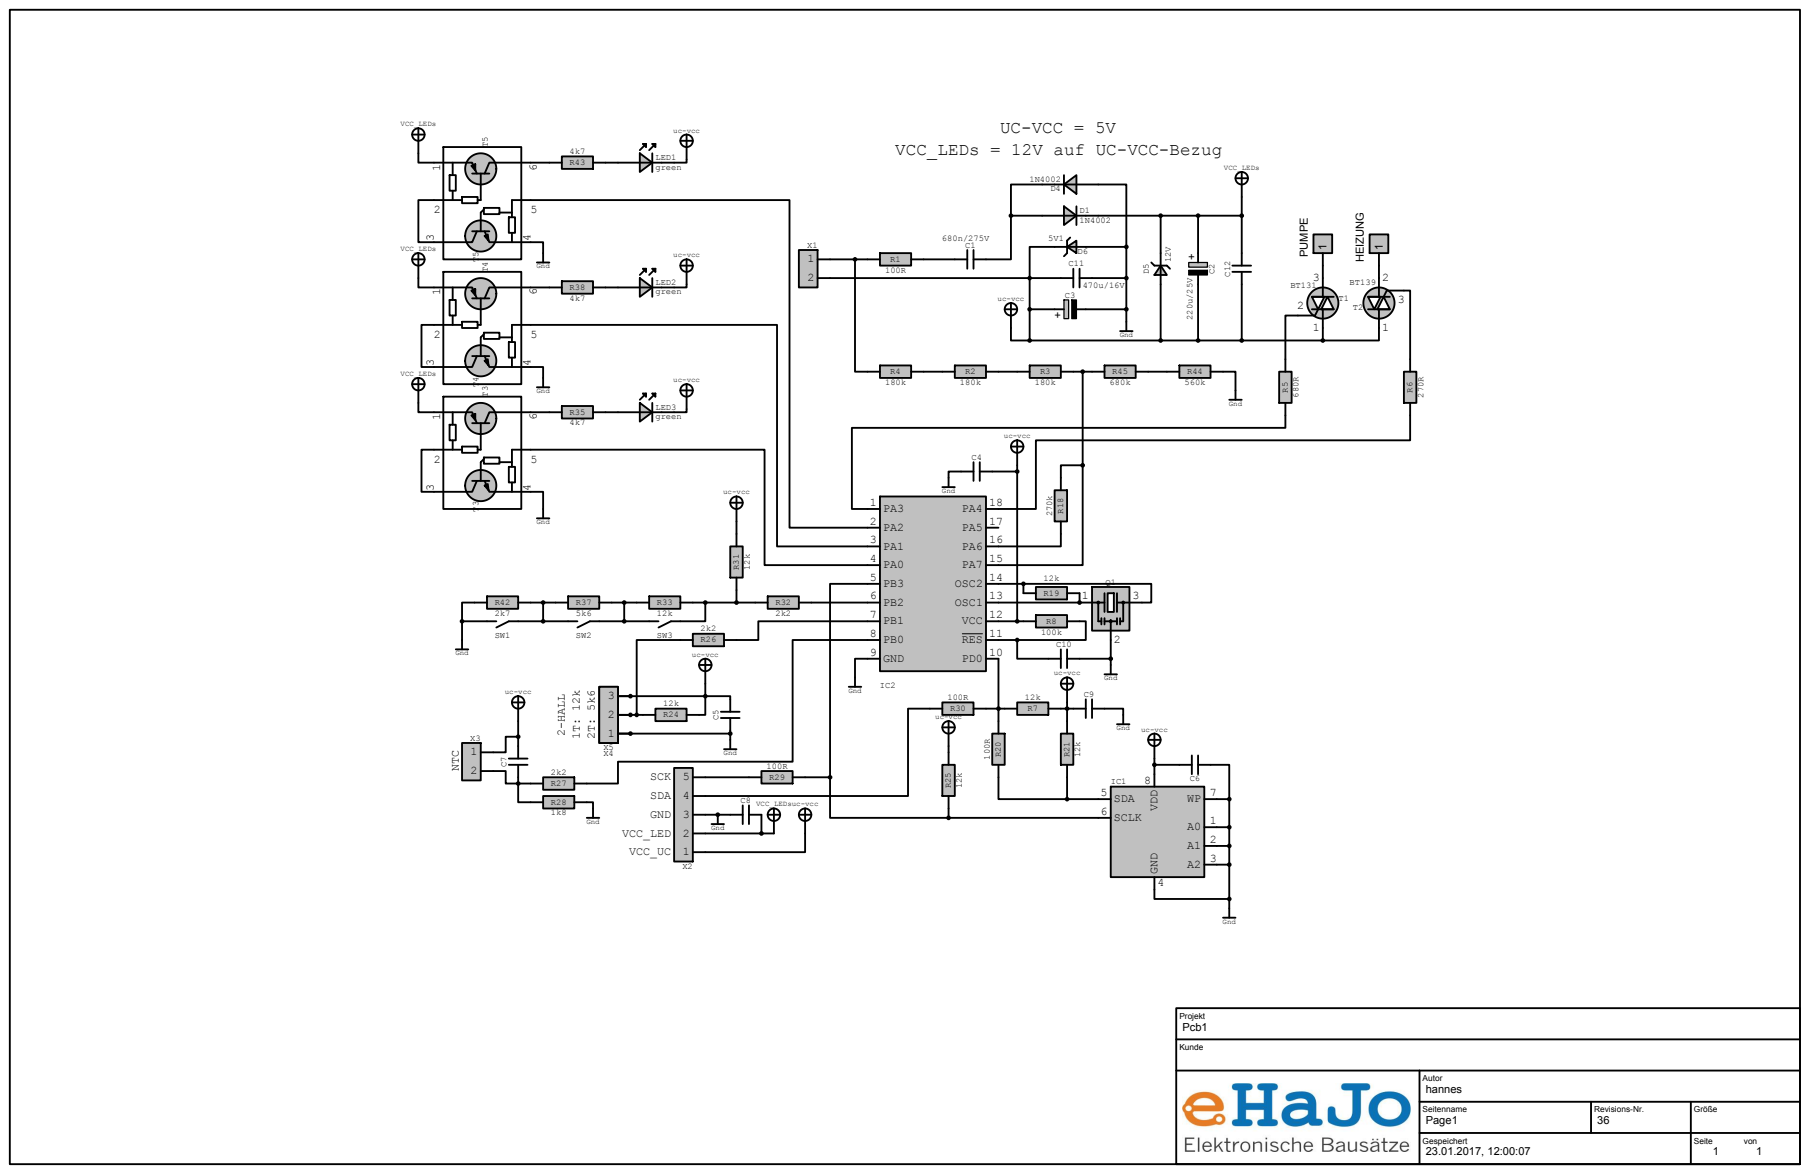
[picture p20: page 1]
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

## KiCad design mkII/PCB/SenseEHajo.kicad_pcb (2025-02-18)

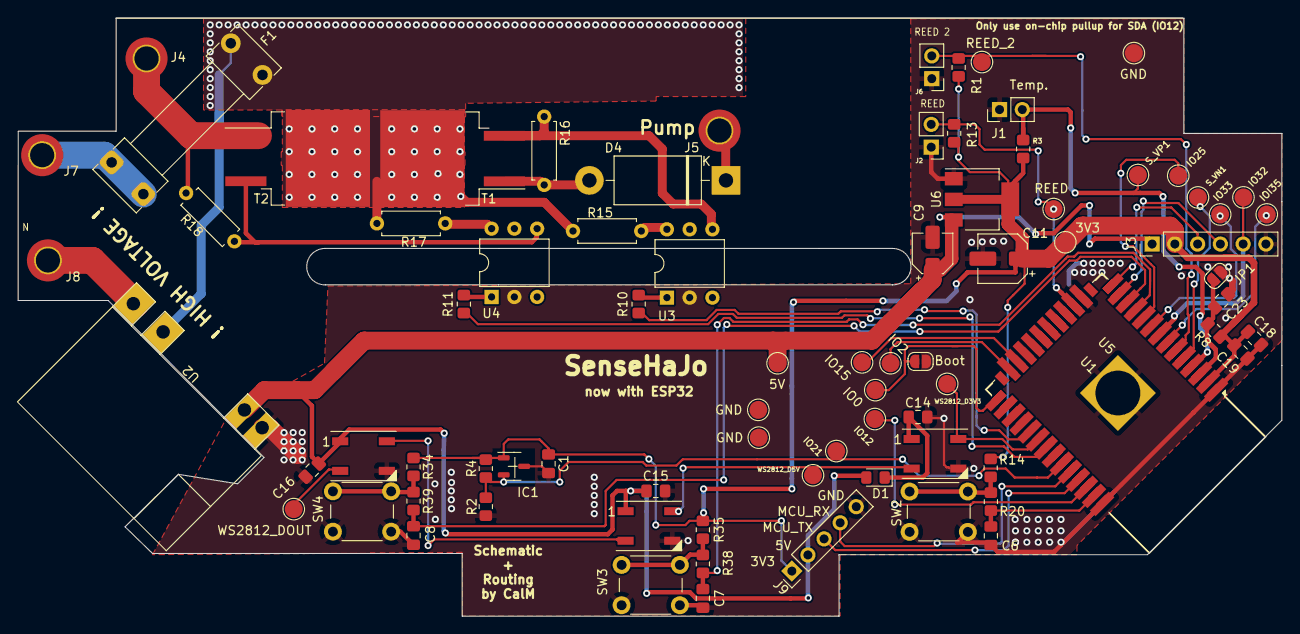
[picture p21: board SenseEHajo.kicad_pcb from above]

Board: 2 copper layers, 141.0 x 66.7 mm, 80 parts (0 on the bottom side), 47 nets.

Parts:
3V3: 3V3; TestPoint_Pad_D2.0mm
5V: 5V; TestPoint_Pad_D2.0mm
C1, C6, C7, C8, C14, C15, C16, C19: 100nF / 10V; C_0805_2012Metric_Pad1.18x1.45mm_HandSolder
C9: 10uF/10V; CP_Elec_4x4.5
C11: 47uF/10V; CP_Elec_5x5.3
C18, C23: 10uF / 10V; C_0805_2012Metric_Pad1.18x1.45mm_HandSolder
D1: 1N4006; D_0805_2012Metric_Pad1.15x1.40mm_HandSolder
D3, D6, D7: WS2812B; WS2812B_SMD_HandSolder
D4: 1N4006; D_DO-201AD_P15.24mm_Horizontal
F1: 0.5A / 230VAC; Fuseholder_Clip-5x20mm_Littelfuse_111_Lateral_P18.80x5.00mm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
GND: 5V; TestPoint_Pad_D2.0mm
GND#2, GND#3: 5V; TestPoint_Pad_D2.0mm
IC1: SL353LT; SOT-23-3
IO0, IO2, IO15, IO21, IO25, IO32, IO33: IO32; TestPoint_Pad_D2.0mm
IO12: I2C_DISP_SDA_3V3; TestPoint_Pad_D2.0mm
IOI35: IO32; TestPoint_Pad_D2.0mm
J1: Conn_01x02_Male; PinHeader_1x02_P2.54mm_Vertical
J2, J6: REED; PinHeader_1x02_P2.54mm_Vertical
J3: RTC ( DS3231); PinHeader_1x06_P2.54mm_Vertical
J4: Heizung L; MountingHole_2.7mm_M2.5_DIN965_Pad_TopBottom
J5: Pumpe L; MountingHole_2.7mm_M2.5_DIN965_Pad_TopBottom
J7: L; MountingHole_2.7mm_M2.5_DIN965_Pad_TopBottom
J8: N; MountingHole_2.7mm_M2.5_DIN965_Pad_TopBottom
J9: Prog; PinHeader_1x05_P2.54mm_Vertical
JP1: Jumper_2_Open; SolderJumper-2_P1.3mm_Open_RoundedPad1.0x1.5mm
JP2: Boot; SolderJumper-2_P1.3mm_Open_RoundedPad1.0x1.5mm
R1, R2, R4, R8, R13, R14, R34, R35: 10k; R_0805_2012Metric_Pad1.20x1.40mm_HandSolder
R3: 3k3/1%; R_0805_2012Metric_Pad1.20x1.40mm_HandSolder
R10, R11: 150R; R_0805_2012Metric_Pad1.20x1.40mm_HandSolder
R15, R17: 360R; R_Axial_DIN0207_L6.3mm_D2.5mm_P7.62mm_Horizontal
R16, R18: 330R; R_Axial_DIN0207_L6.3mm_D2.5mm_P7.62mm_Horizontal
R20, R38, R39: 1k; R_0805_2012Metric_Pad1.20x1.40mm_HandSolder
REED: IO32; TestPoint_Pad_D2.0mm
REED_2: IO32; TestPoint_Pad_D2.0mm
SW2: SW1 ( Boot ); SW_PUSH_6mm
SW3: MACHINE_SW2; SW_PUSH_6mm
SW4: MACHINE_SW3; SW_PUSH_6mm
S_VN1: IO32; TestPoint_Pad_D2.0mm
S_VP1: IO32; TestPoint_Pad_D2.0mm
T1, T2: QJ8025; TO-263-3_TabPin2
U1: ESP32-WROOM-32; ESP32-WROOM-32_HandSolder
U2: SKU011012
U3, U4: MOC3043M; DIP-6_W7.62mm
U5: ESP32-S3-WROOM-1
U6: LM1117-3.3; SOT-223-3_TabPin2
WS2812_D3V3, WS2812_D5V, WS2812_DOUT: TestPoint; TestPoint_Pad_D2.0mm

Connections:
+3V3: 3V3.1, C1.1, C11.1, C18.2, C19.2, IC1.1 (VCC), J3.2, J9.1, R1.1, R3.1, R4.1, R8.1, R13.1, R14.1, R34.1, R35.1, U1.2 (VDD), U6.2 (VO)
+5V: 5V.1, C9.1, C15.1, C16.1, D1.2 (A), D6.1 (VDD), D7.1 (VDD), J3.1, J9.2, U2.4 (5V), U6.3 (VI)
EN: C23.1, JP1.2 (B), R8.2, U1.3 (EN)
ESP32_ADC: J1.2, R3.2, S_VP1.1, U1.4 (SENSOR_VP)
GND: C1.2, C6.1, C7.1, C8.1, C9.2, C11.2, C14.2, C15.2, C16.2, C18.1, C19.1, C23.2, D3.3 (VSS), D6.3 (VSS), D7.3 (VSS), GND.1, IC1.3 (GND), J1.1, J2.1, J3.6, J6.1, J9.5, JP1.1 (A), JP2.2 (B), R2.2, SW2.2, SW3.2, SW4.2, U1.1 (GND), U1.15 (GND), U1.38 (GND), U1.39 (GND), U2.3 (GND), U3.2, U4.2, U6.1 (GND)
HAL_SENSOR: IC1.2 (OUTPUT), IO21.1, R2.1, R4.2, U1.33 (IO21)
Heizung_MOC: R11.2, U1.31 (IO19)
I2C_DSP_SCL: IO0.1, JP2.1 (A), U1.25 (IO0)
I2C_DSP_SDA: IO12.1, U1.36 (IO22)
IO32: IO32.1, J3.5, U1.8 (IO32)
LOAD_230V: F1.2, R15.2, R17.2, T1.2 (A2), T2.2 (A2), U2.2 (N)
L_230V: F1.1, J7.1
MCU_RX: J9.4, U1.34 (RXD0/IO3)
MCU_TX: J9.3, U1.35 (TXD0/IO1)
N_230V: J8.1, U2.1 (L)
unnamed: C14.1, D1.1 (K), D3.1 (VDD)
unnamed: D3.2 (DOUT), D6.4 (DIN), WS2812_D5V.1
unnamed: D4.2 (A), R16.2, T1.1 (A1)
unnamed: D4.1 (K), J5.1
unnamed: D6.2 (DOUT), D7.4 (DIN)
unnamed: D7.2 (DOUT), WS2812_DOUT.1
unnamed: J4.1, R18.2, T2.1 (A1)
unnamed: R10.1, U3.1
unnamed: R11.1, U4.1
unnamed: R14.2, R20.1, SW2.1
unnamed: R15.1, U3.6
unnamed: R17.1, U4.6
unnamed: R34.2, R39.1, SW4.1
unnamed: R35.2, R38.1, SW3.1
unnamed: R16.1, T1.3 (G), U3.4
unnamed: R18.1, T2.3 (G), U4.4
unnamed: IO2.1, U1.24 (IO2)
unnamed: IO15.1, U1.23 (IO15)
unnamed: C6.2, R20.2, U1.37 (IO23)
unnamed: IO25.1, U1.10 (IO25)
unnamed: C7.2, R38.2, U1.11 (IO26)
unnamed: C8.2, R39.2, U1.12 (IO27)
unnamed: IO33.1, U1.9 (IO33)
unnamed: IOI35.1, U1.7 (IO35)
unnamed: S_VN1.1, U1.5 (SENSOR_VN)
unnamed: U5.1 (GND), U5.40 (GND), U5.41 (GND)
PUMP_MOC: R10.2, U1.29 (IO5)
REED_IN: J2.2, R13.2, REED.1, U1.16 (IO13)
REED_IN_2: J6.2, R1.2, REED_2.1, U1.6 (IO34)
SCL_3V3: J3.4, U1.13 (IO14)
SDA_3V3: J3.3, U1.14 (IO12)
WS2812_3V3: D3.4 (DIN), U1.30 (IO18), WS2812_D3V3.1

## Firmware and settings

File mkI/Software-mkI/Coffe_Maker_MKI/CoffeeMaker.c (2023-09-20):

/*
 * main.c
 *
 * Created: 24.03.2017 19:08:59
 * Author: Mathias Claußen aka calm
 */ 

/*
* www.eHaJo.de
* All rights reserved
* (C) 2016-2017
*/

#include "CoffeeMaker.h"

#include "./driver/MCP3202/MCP3202.h"
#include "./driver/gpio/gpio.h"
#include "./driver/USART_SPI_Master/HW_USART_SPI.h"
#include "./driver/Timer/Timer.h"
#include "./driver/SWI2C_special/i2cmaster.h"


#include "../../services/boilertemp/boilertemp.h"
#include "../../services/powermeter/powermeter.h"

#include "../../services/eepromFileSystem/eepromFileSystem.h"
#include "../../services/buttondriver/buttondriver.h"
#include "../../services/pumpservice/pumpservice.h"
#include "../../services/heaterservice/heaterservice.h"
#include "../../services/coffee_fsm/coffee_fsm.h"
#include "../../services/boilertempcontroller/boilertempcontroller.h"
#include "../../services/TimerService/TimerService.h"
#include "../../services/displayservice/displayservice.h"
#include "../../services/heaterpowercontroller/heaterpowercontroller.h"
#include "../../services/lightningservice/ledlightningservice.h"
#include "../../services/healthmonitor/healthmonitor.h"
#include "../../services/CommandInterpreter/CommandInterpreter.h"
#include "../../services/waterlevelmessurment/waterlevelmessurment.h"
#include "../../services/usb_cdc_helper/usb_cdc_helper.h"

/** LUFA CDC Class driver interface configuration and state information. This structure is
 *  passed to all CDC Class driver functions, so that multiple instances of the same class
 *  within a device can be differentiated from one another.
 */
USB_ClassInfo_CDC_Device_t VirtualSerial_CDC_Interface =
	{
		.Config =
			{
				.ControlInterfaceNumber   = INTERFACE_ID_CDC_CCI,
				.DataINEndpoint           =
					{
						.Address          = CDC_TX_EPADDR,
						.Size             = CDC_TXRX_EPSIZE,
						.Banks            = 1,
					},
				.DataOUTEndpoint =
					{
						.Address          = CDC_RX_EPADDR,
						.Size             = CDC_TXRX_EPSIZE,
						.Banks            = 1,
					},
				.NotificationEndpoint =
					{
						.Address          = CDC_NOTIFICATION_EPADDR,
						.Size             = CDC_NOTIFICATION_EPSIZE,
						.Banks            = 1,
					},
			},
	};

/** Standard file stream for the CDC interface when set up, so that the virtual CDC COM port can be
 *  used like any regular character stream in the C APIs.
 */

typedef void (*VoidFnct) (void);


typedef struct {
	uint16_t u16_lastrun;
	uint16_t u16_intervall;
	uint8_t RunRequiered;
	VoidFnct fncptrCallBack;
} TIMEROBJ_t;


void voScheduler( void );
void voUSB_Task( void );
void voMS100_Tasks ( void );
void voMS10_Tasks ( void );
void voMS50_Tasks ( void );
void voMS1_Task ( void );
void voMS1000_Tasks ( void );



/* Main entry point, this also start the scheduler for some tasks

While we have no RTOS on this MCU, we still need to execute some
task in an organized fashion. This is done by the "scheduler" but
not one you would find in an RTOS. This one is very simple and
will require things to be handled in the super loop. 

What it is doing is calling a set of functions at a given point
in time to produce some cooperative tasking. 

TIMEROBJ_t Timer_OBJ[] holds an array of functions to be called at
certain intervals (in ms). In these functions all tasks that need
to be run in certain intervals will be called.

All is organized by voScheduler() that uses a timer to keep track
which task needs to be run next
 
*/

int main(void)
{
	SetupHardware();
	//We need to wait a few seconds until all pins are stable
	for(uint8_t i=0; i<20;i++ ){
		_delay_ms(100);
	}
	//Next is to power up the machine
	voEEFS_Init();
	/* Create a regular character stream for the interface so that it can be used with the stdio.h functions */
	FILE USBSerialStream;
	CDC_Device_CreateStream(&VirtualSerial_CDC_Interface, &USBSerialStream);
	voSetUSBStream(USBSerialStream);
	GlobalInterruptEnable();
	voInit_HwTimer();
	
	/* Service init */
	voBLTMP_InitBoilerTemp();
	voPWRMTR_InitPowermeter();
	
	/* Setup the Tasks */
	voHPC_TaskInit();
	voHMon_Init();
	voKeyEvent_TaskInit();
	voPSE_TaskInit();
	voCoffeeFSM_TaskInit();
	voBTC_TaskInit();
	voTMS_InitTask();
	
	LLS_voInitTask();
	DPS_Init();
	i2c_init();
	CMDI_voInit();
	
	

	
	boCoffeeFSM_LoadProgramm(0);
	voCoffeeFSM_LoadSystemSettings();
	while( 1==1 ) 
	{
		
		voScheduler();
		voUSB_Task();
		CMDI_voTask();
	}
}



void voUSB_Task(  )
{
	/* Must throw away unused bytes from the host, or it will lock up while waiting for the device */
	int16_t Data = CDC_Device_ReceiveByte(&VirtualSerial_CDC_Interface);
	if(Data >= 0)
	{
		/* We need to colect the Data for processing here */
		CMDI_boAddCharToBuffer(Data);
		/* First we put the Data to the FiFo and execute the Data if we find an Enter */
	}
	CDC_Device_USBTask(&VirtualSerial_CDC_Interface);
	USB_USBTask();
}

/* This is currently prone to jitter and drift*/
void voProcessTimerOBJ(volatile TIMEROBJ_t* ptrTimerOBJ ){

uint16_t u16_current_time=u16GetSystemTicksMS();
/* Here we execute the Coffemaker parts if requiered */
uint16_t u16Delta = 0;
/* We need to move the Time axis here */


uint16_t u16intervall = ptrTimerOBJ->u16_intervall;
/* Everything here is run at XXXms Slots */
	if(ptrTimerOBJ->u16_intervall>0){
		/* Everything here is run at XXXms Slots */
		if(ptrTimerOBJ->u16_lastrun > u16_current_time ){
			/* our time delta is now  ( UINT16_MAX - u16_lastrun ) + u16_current_time */
			u16Delta = ( ( UINT16_MAX - ptrTimerOBJ->u16_lastrun) +u16_current_time  );
			if( u16Delta > u16intervall){
				ptrTimerOBJ->RunRequiered=1;
				/* ptrTimerOBJ->u16_lastrun = u16_current_time; */
				/* This will fix the drift */
				ptrTimerOBJ->u16_lastrun = ptrTimerOBJ->u16_lastrun+ptrTimerOBJ->u16_intervall;
			}
		} else {
			/* our delta is u16current_time - u16_lastrun */
			u16Delta = ( u16_current_time -ptrTimerOBJ->u16_lastrun  ) ;
			if( u16Delta > u16intervall ){
				ptrTimerOBJ->RunRequiered=1;
				/* ptrTimerOBJ->u16_lastrun = u16_current_time; */
				/* This will fix the drift */
				ptrTimerOBJ->u16_lastrun = ptrTimerOBJ->u16_lastrun+ptrTimerOBJ->u16_intervall;
			}
		}
	}
}

/* Little dirty define for Timer */
#define TIMER( Period , CallBack) {0, Period , 0 , CallBack }
/* The Table needs to be placed in RAM as we store some additional information during runtime in it */
volatile TIMEROBJ_t Timer_OBJ[] = {
	
	TIMER(1,   voMS1_Task),
	TIMER(10,  voMS10_Tasks  ),		/* 10ms Timer */
	TIMER(100, voMS100_Tasks ),		/* 100ms Timer */
	TIMER(50,  voMS50_Tasks  ),		/* 50ms Timer */
	TIMER(1000, voMS1000_Tasks ),	/* 1000ms Timer */

};


void voScheduler( ) {

uint8_t u8NoOfTimer= (sizeof(Timer_OBJ)/sizeof(TIMEROBJ_t));

for(uint8_t i=0;i<u8NoOfTimer;i++){
	voProcessTimerOBJ(&Timer_OBJ[i]);
	if(Timer_OBJ[i].RunRequiered!=0){
		if(Timer_OBJ[i].fncptrCallBack!=NULL){
			Timer_OBJ[i].fncptrCallBack();
		}
		Timer_OBJ[i].RunRequiered=0;
	}
}

/* This is the run always part for the USB Stack */
voUSB_Task();
		
	
}

void voMS1_Task( void ){
	
	
	
}

void voMS10_Tasks(void){
	voKeyEvent_Task();
	
}

void voMS100_Tasks(void){
	WLM_voTask();
	voTMS_Task();
	voPSE_Task();
	voBTC_Task();
	
	voHMon_Task();
	voCoffeeFSM_Task();
	
}

void voMS50_Tasks(void){
	/* We will update the Display here and may even handle Blinking ICONs */
	DPS_voTask();
	LLS_voTask();
	
	
}

void voMS1000_Tasks(){
	
}


/* Configuration for the MkI Hardware */
void SetupHardware(void)
{
#if (ARCH == ARCH_AVR8)
	/* Disable watchdog if enabled by bootloader/fuses */
	MCUSR &= ~(1 << WDRF);
	wdt_disable();

	/* Disable clock division */
	clock_prescale_set(clock_div_1);
#elif (ARCH == ARCH_XMEGA)
	#error "ARCH NOT SUPPORTED BY COFFEE MAKER MKI"
#endif

	/* Hardware Initialization */
	USB_Init();
	
	GPIO_Init();
	voSetPumpPowerState(POWER_OFF);
	voSetHeaterPowerState(POWER_OFF);
	
	voSetLedState(0,LED_OFF);
	voSetLedState(1,LED_OFF);
	voSetLedState(2,LED_OFF);
	
	
	voMCP3202_Init();
	
}

/** Event handler for the library USB Connection event. */
void EVENT_USB_Device_Connect(void)
{
	voSetConnected(true);
	
}

/** Event handler for the library USB Disconnection event. */
void EVENT_USB_Device_Disconnect(void)
{
	voSetConnected(false);
}

/** Event handler for the library USB Configuration Changed event. */
void EVENT_USB_Device_ConfigurationChanged(void)
{
	bool ConfigSuccess = true;

	ConfigSuccess &= CDC_Device_ConfigureEndpoints(&VirtualSerial_CDC_Interface);

	
}

/** Event handler for the library USB Control Request reception event. */
void EVENT_USB_Device_ControlRequest(void)
{
	CDC_Device_ProcessControlRequest(&VirtualSerial_CDC_Interface);
}

/** CDC class driver callback function the processing of changes to the virtual
 *  control lines sent from the host..
 *
 *  \param[in] CDCInterfaceInfo  Pointer to the CDC class interface configuration structure being referenced
 */
void EVENT_CDC_Device_ControLineStateChanged(USB_ClassInfo_CDC_Device_t *const CDCInterfaceInfo)
{
	/* You can get changes to the virtual CDC lines in this callback; a common
	   use-case is to use the Data Terminal Ready (DTR) flag to enable and
	   disable CDC communications in your application when set to avoid the
	   application blocking while waiting for a host to become ready and read
	   in the pending data from the USB endpoints.
	*/
	__attribute__ ((unused)) bool HostReady = (CDCInterfaceInfo->State.ControlLineStates.HostToDevice & CDC_CONTROL_LINE_OUT_DTR) != 0;
}

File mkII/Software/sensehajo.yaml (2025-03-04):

esphome:
  name: sensehajo
  friendly_name: SenseHaJo
  project:
    name: "eHaJo.SenseHaJo"
    version: "0.1.0"
  on_boot:
    then:
      - delay: 2s  # Zeige das Logo für 2 Sekunden
      - lambda: |-
          id(boot_finished) = true;
      - script.execute: script_all_off

esp32:
  board: esp32dev
  framework:
    type: arduino

logger:
  level: INFO

i2c:
  sda: GPIO32
  scl: GPIO14
  frequency: 200kHz

# Bildressource definieren
image:
  - file: "ehajo_bw.xbm"
    id: ehajo_bw
    type: BINARY

display:
  - platform: ssd1306_i2c
    model: "SSD1306 128x64"
    address: 0x3C
    id: oled_display
    update_interval: 1s
    lambda: |-
      if (id(boot_finished)) {
        it.printf(20, 0, id(font_large), "SenseHaJo");
        it.printf(15, 16, id(font_small), "Boiler: %.1f°C", id(sensor_boilertemp).state);
        switch(id(_sensehajo_state)) {
          case 0: it.print(52, 48, id(font_small), "AUS"); break;
          case 10: it.print(47, 48, id(font_small), "STBY"); break;
          case 15: it.print(42, 48, id(font_small), "READY"); break;
          case 20: it.print(42, 48, id(font_small), "Kochen"); break;
          case 40: it.print(42, 48, id(font_small), "Spülen"); break;
          case 100: it.print(42, 48, id(font_small), "Error"); break;
        }
      }
      else {
        it.image(0, 0, id(ehajo_bw));
      }

font:
  - file: "courbd.ttf"
    id: font_large
    size: 16
  - file: "courbd.ttf"
    id: font_small
    size: 12

api:
  encryption:
    key: !secret api-key

ota:
  - platform: esphome
    password: !secret ota-pw

wifi:
  ssid: !secret wifi_ssid
  password: !secret wifi_password
  ap:
    ssid: "Sensehajo Fallback Hotspot"
    password: !secret fallback-pw

captive_portal:

globals:
  - id: _sensehajo_state
    type: int
    restore_value: no
    initial_value: '0'
    #  0 ... AUS
    # 10 ... STBY
    # 15 ... READY
    # 20 ... Kaffee kochen
    # 25 ... Aufheizen - Kaffee - Aus
    # 40 ... Spülen
    # 100 ... error
  - id: boot_finished  # Neue Variable für Boot-Status
    type: bool
    restore_value: no
    initial_value: 'false'

light:
  - platform: neopixelbus
    id: "sensehajo_ws2812"
    type: GRB
    variant: WS2812
    pin: GPIO18
    num_leds: 3
  - platform: partition
    id: "sensehajo_LED1"
    default_transition_length: 0s
    segments:
      - id: sensehajo_ws2812
        from: 0
        to: 0
    effects:
      - random:
          name: "Kaffeekochen"
          transition_length: 0.5s
          update_interval: 0.5s
      - pulse:
          name: "Kaffeewarten"
          transition_length: 0.3s
          update_interval: 0.3s
          min_brightness: 20%
          max_brightness: 50%
  - platform: partition
    id: "sensehajo_LED2"
    default_transition_length: 0s
    segments:
      - id: sensehajo_ws2812
        from: 1
        to: 1
    effects:
      - random:
          name: "Spuelen"
          transition_length: 0.5s
          update_interval: 0.5s
      - pulse:
          name: "Fast Pulse"
          transition_length: 0.3s
          update_interval: 0.3s
          min_brightness: 20%
          max_brightness: 50%
  - platform: partition
    id: "sensehajo_LED3"
    default_transition_length: 0s
    segments:
      - id: sensehajo_ws2812
        from: 2
        to: 2
    effects:
      - random:
          name: "Kaffeekochen"
          transition_length: 0.5s
          update_interval: 0.5s
      - pulse:
          name: "Kaffeewarten"
          transition_length: 0.3s
          update_interval: 0.3s
          min_brightness: 20%
          max_brightness: 50%

number:
  - platform: template
    id: sensehajo_bruehzeit
    name: "Brühzeit"
    icon: mdi:timer-cog-outline
    min_value: 1
    max_value: 30
    step: 1
    restore_value: true
    optimistic: true
    unit_of_measurement: "s"
  - platform: template
    id: sensehajo_kaffeetemp
    name: "Brühtemperatur"
    icon: mdi:water-thermometer
    min_value: 50
    max_value: 90
    restore_value: true
    step: 1
    optimistic: true
    unit_of_measurement: "°C"

button:
  - platform: template
    name: "SenseHaJo einschalten"
    id: button_turnON
    icon: "mdi:power"
    on_press:
      - script.execute: script_power_on
  - platform: template
    name: "1 Tasse Kaffee"
    id: button_1coffee
    icon: "mdi:coffee"
    on_press:
      - script.execute:
          id: script_prepare_coffee
          cups: 1
  - platform: template
    name: "2 Tassen Kaffee"
    id: button_2coffee
    icon: "mdi:coffee"
    on_press:
      - script.execute:
          id: script_prepare_coffee
          cups: 2
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

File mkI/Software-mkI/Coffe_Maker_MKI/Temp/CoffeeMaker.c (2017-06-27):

/*
             LUFA Library
     Copyright (C) Dean Camera, 2015.

  dean [at] fourwalledcubicle [dot] com
           www.lufa-lib.org
*/

/*
  Copyright 2015  Dean Camera (dean [at] fourwalledcubicle [dot] com)

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
  The author disclaims all warranties with regard to this
  software, including all implied warranties of merchantability
  and fitness.  In no event shall the author be liable for any
  special, indirect or consequential damages or any damages
  whatsoever resulting from loss of use, data or profits, whether
  in an action of contract, negligence or other tortious action,
  arising out of or in connection with the use or performance of
  this software.
*/

/** \file
 *
 *  Main source file for the VirtualSerial demo. This file contains the main tasks of
 *  the demo and is responsible for the initial application hardware configuration.
 */

#include "CoffeeMaker.h"

#include "./driver/MCP3202/MCP3202.h"
#include "./driver/gpio/gpio.h"
#include "./driver/USART_SPI_Master/HW_USART_SPI.h"
#include "./driver/Timer/Timer.h"

#include "../../services/boilertemp/boilertemp.h"
#include "../../services/powermeter/powermeter.h"

#include "../../services/buttondriver/buttondriver.h"
#include "../../services/pumpservice/pumpservice.h"
#include "../../services/heaterservice/heaterservice.h"
#include "../../services/coffee_fsm/coffee_fsm.h"
#include "../../services/boilertempcontroller/boilertempcontroller.h"
#include "../../services/heaterpowercontroller/heaterpowercontroller.h"

/** LUFA CDC Class driver interface configuration and state information. This structure is
 *  passed to all CDC Class driver functions, so that multiple instances of the same class
 *  within a device can be differentiated from one another.
 */
/** LUFA CDC Class driver interface configuration and state information. This structure is
 *  passed to all CDC Class driver functions, so that multiple instances of the same class
 *  within a device can be differentiated from one another. This is for the first CDC interface,
 *  which sends strings to the host for each joystick movement.
 */
USB_ClassInfo_CDC_Device_t VirtualSerial1_CDC_Interface =
	{
		.Config =
			{
				.ControlInterfaceNumber   = INTERFACE_ID_CDC1_CCI,
				.DataINEndpoint           =
					{
						.Address          = CDC1_TX_EPADDR,
						.Size             = CDC_TXRX_EPSIZE,
						.Banks            = 1,
					},
				.DataOUTEndpoint =
					{
						.Address          = CDC1_RX_EPADDR,
						.Size             = CDC_TXRX_EPSIZE,
						.Banks            = 1,
					},
				.NotificationEndpoint =
					{
						.Address          = CDC1_NOTIFICATION_EPADDR,
						.Size             = CDC_NOTIFICATION_EPSIZE,
						.Banks            = 1,
					},
			},
	};

/** LUFA CDC Class driver interface configuration and state information. This structure is
 *  passed to all CDC Class driver functions, so that multiple instances of the same class
 *  within a device can be differentiated from one another. This is for the second CDC interface,
 *  which echos back all received data from the host.
 */
USB_ClassInfo_CDC_Device_t VirtualSerial2_CDC_Interface =
	{
		.Config =
			{
				.ControlInterfaceNumber   = INTERFACE_ID_CDC2_CCI,
				.DataINEndpoint           =
					{
						.Address          = CDC2_TX_EPADDR,
						.Size             = CDC_TXRX_EPSIZE,
						.Banks            = 1,
					},
				.DataOUTEndpoint =
					{
						.Address          = CDC2_RX_EPADDR,
						.Size             = CDC_TXRX_EPSIZE,
						.Banks            = 1,
					},
				.NotificationEndpoint =
					{
						.Address          = CDC2_NOTIFICATION_EPADDR,
						.Size             = CDC_NOTIFICATION_EPSIZE,
						.Banks            = 1,
					},

			},
	};


/** Standard file stream for the CDC interface when set up, so that the virtual CDC COM port can be
 *  used like any regular character stream in the C APIs.
 */
void voScheduler( void );

FILE USBSerialStream_1;
static FILE USBSerialStream_2;
volatile uint8_t connected=0;


/** Main program entry point. This routine contains the overall program flow, including initial
 *  setup of all components and the main program loop.
 */
int main(void)
{
	SetupHardware();
	
	/* Create a regular character stream for the interface so that it can be used with the stdio.h functions */
	CDC_Device_CreateStream(&VirtualSerial1_CDC_Interface, &USBSerialStream_1);
	CDC_Device_CreateStream(&VirtualSerial2_CDC_Interface, &USBSerialStream_2);
	GlobalInterruptEnable();
	timer1_setup();
	
	/* Service init */
	voBLTMP_InitBoilerTemp();
	voPWRMTR_InitPowermeter();
	
	/* Setup the Tasks */
	voHPC_TaskInit();
	voKeyEvent_TaskInit();
	voPSE_TaskInit();
	voCoffeeFSM_TaskInit();
	voBTC_TaskInit();
	
	while( 1==1 ) 
	{
		
	voScheduler();
	
		
	}
}


uint8_t  voCheckIfRunRequiered(uint16_t delta , uint16_t u16_current_time , uint16_t* u16_lastrun ) 
{																						
	if(*u16_lastrun > u16_current_time ){

		if( ( ( UINT16_MAX - *u16_lastrun) +u16_current_time  ) > 10 ){
			*u16_lastrun = u16_current_time;
			return 1;
		}
		
	} else {

		if( ( u16_current_time -*u16_lastrun  ) > 10 ){
			return 1;
			*u16_lastrun = u16_current_time;
		}

	}
	
	return 1;
}
void voScheduler( ) {
static uint16_t u16_10ms_lastrun=0;
static uint16_t u16_100ms_lastrun=0;
static uint16_t u16_200ms_lastrun=0;

struct {
	uint8_t bf10msRunRequiered:1;
	uint8_t bf100msRunRequiered:1;
	uint8_t bf200msRunRequiered:1;
	uint8_t bfReserved:5;
} RunFlags;

uint16_t u16_current_time=u16GetSystemTicksMS();	
/* Here we execute the Coffemaker parts if requiered */


/* Everything here is run at 10ms Slots */
if(u16_10ms_lastrun > u16_current_time ){
	/* our timedelta is now  ( UINT16_MAX - u16_10ms_lastrun ) + u16_current_time */
	if( ( ( UINT16_MAX - u16_10ms_lastrun) +u16_current_time  ) > 10 ){
		RunFlags.bf10msRunRequiered=1;
		u16_10ms_lastrun = u16_current_time;
	} 
} else {
	/* our delta is u16current_time - u16_10ms_lastrun */
	if( ( u16_current_time -u16_10ms_lastrun  ) > 10 ){
		RunFlags.bf10msRunRequiered=1;
		u16_10ms_lastrun = u16_current_time;
	}
}

/* Everything here is run at 10ms Slots */
if(u16_100ms_lastrun > u16_current_time ){
	/* our timedelta is now  ( UINT16_MAX - u16_10ms_lastrun ) + u16_current_time */
	if( ( ( UINT16_MAX - u16_100ms_lastrun) +u16_current_time  ) > 100){
		RunFlags.bf100msRunRequiered=1;
		u16_100ms_lastrun = u16_current_time;
	}
	} else {
	/* our delta is u16current_time - u16_10ms_lastrun */
	if( ( u16_current_time -u16_100ms_lastrun  ) > 100 ){
		RunFlags.bf100msRunRequiered=1;
		u16_100ms_lastrun = u16_current_time;
	}
}
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

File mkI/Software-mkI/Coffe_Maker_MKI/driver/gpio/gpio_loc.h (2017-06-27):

/*
 * gpio.h
 *
 * Created: 20.09.2013 14:53:45
 *  Author: calm
 */ 

  /*
  * www.eHaJo.de
  * All rights reserved
  * (C) 2016-2017
  */


#ifndef GPIO_LOC_H_
#define GPIO_LOC_H_


/* The three Fron LEDs */
#define LED3 PORTB6
#define LED3_DDR DDRB
#define LED3_PORT PORTB
#define LED3_PIN PINB

#define LED2 PORTB4
#define LED2_DDR DDRB
#define LED2_PORT PORTB
#define LED2_PIN PINB

#define LED1 PORTD7
#define LED1_DDR DDRD
#define LED1_PORT PORTD
#define LED1_PIN PIND

/* The three Front Switches */
/* These need PullUps enabeld */
#define SWITCH1 PORTB0
#define SWITCH1_DDR DDRB
#define SWITCH1_PORT PORTB
#define SWITCH1_PIN PINB

#define SWITCH2 PORTB5
#define SWITCH2_DDR DDRB
#define SWITCH2_PORT PORTB
#define SWITCH2_PIN PINB

#define SWITCH3 PORTB7
#define SWITCH3_DDR DDRB
#define SWITCH3_PORT PORTB
#define SWITCH3_PIN PINB

/* The next two are the HAL Sensors for the Waterlevel */
/* Those need a PULLUP active */
#define HALL_SW1 PORTC6
#define HALL_SW1_DDR DDRC
#define HALL_SW1_PORT PORTC
#define HALL_SW1_PIN PINC

#define HALL_SW2 PORTC7
#define HALL_SW2_DDR DDRC
#define HALL_SW2_PORT PORTC
#define HALL_SW2_PIN PINC

#define HEATER PORTD1
#define HEATER_DDR DDRD
#define HEATER_PORT PORTD
#define HEATER_PIN PIND

#define PUMP PORTD0
#define PUMP_DDR DDRD
#define PUMP_PORT PORTD
#define PUMP_PIN PIND


/* This are the Strict GPIOs for now */
/* Other Pins will be set by there corresponding drivers */



#endif /* GPIO_LOC_H_ */

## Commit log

2023-08-19 update button driver
    Update
2023-09-12 Bugfix for commands
    Resolves bug that prevents compiling
    [CommandInterpreter.c]
2023-09-12 Fix GET GPIO
    Shall fix GET GPIO X command
    [CommandInterpreter.c]
2023-09-12 Updates switch commands
    Should fix command GPIO
    [CommandInterpreter.c]
2023-09-16 Refactor of Commands in Command interpreter
    Refactored Commands in Command interprerter
    Also some minor bug fixes
    [CMDI_GPIO.c, CoffeeMaker.c, CommandInterpreter.c]
2023-09-20 Debug session
    Some changes for power on on reset. not working yet.
2024-02-08 Alles Neu
    Neue Ordnerstruktur etc
    [Pcb1.sch, Widerstandswerte.ods, display-protocol.ods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]
2024-02-09 mkI upload
    Upload der PCB Daten von mkI
    [3d-abdeckung.stp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]
2024-04-17 Add submodules for ESP32 version
    Add submodules for ESP32 Version
2024-05-15 Initial Commit
    Streamfortschritt von esphome und unseren überlegungen zu der statemachine
2025-02-18 Moved files. Sorted etc.
    [SenseEHajo-B_Cu.gbl, SenseEHajo-B_Mask.gbs, SenseEHajo-B_Paste.gbp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]
2025-02-25 initial commit
    Rahmen für OLED-Display für Deckel, damit der Rand schön schwarz ist.
    [rahmen-display.stp]
2025-02-25 Aktuelle Version Stream 24.02.
    Display wird nun korrekt angesteuert und zeigt Werte an
2025-02-28 massive update
    - heizungsregelung angepasst von grok auf scripting statt climate.
    - displayansteuerung implementiert und funktional
